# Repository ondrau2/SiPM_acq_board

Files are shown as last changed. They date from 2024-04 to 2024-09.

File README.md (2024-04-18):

Title: Compact multi-channel analyzer for SiPM detectors with real time on-board signal analysis

Most of the commercially available MCAs for SiPM detectors provide precision spectral measurements with costly high-end components. These devices are ideal for accurate instrumentation, however the high complexity makes these devices costly and thus unavailable to wider public. 

The main idea of the presented device is to develop a low-cost MCA which uses widely available of-the-shelf components while providing a spectroscopy of gamma particles with reasonable resolution. The device is based on a STM32G4 family microcontroller, which comprises precision timers with sub-nanosecond resolution, internal embedded analog amplifiers, comparators and up to 4MHz ADC. This significantly reduces required number of external components lowering price and increasing reliability. 

The measurement can be configured by user and may use up to three simultaneous ToT measurements with configurable threshold levels, pulse height measurement, or combination of both. The pulse approximation based on the measured parameters can also be performed to provide peak area measurement. Results can be acquired using various connectivity possibilities such as USB, Ethernet or WiFi. Thanks to the server running on the device the measurement information can be accessed from an internet browser. With an on-board bias power supply only an external power adapter and a SiPM detector with scintillator is needed for measurement.

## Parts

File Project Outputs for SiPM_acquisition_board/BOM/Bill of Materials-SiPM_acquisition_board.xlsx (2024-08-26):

Quantity | Comment | Package | Designator | Distributor | Part Number | Link
40 | 100nF/50V/X7R | 0603 | C1, C4, C5, C11, C25, C28, C30, C32, C43, C44, C45, C46, C55, C56, C57, C58, C68, C69, C71, C72, C74, C75, C76, C77, C78, C84, C86, C89, C91, C94, C96, C99, C102, C105, C107, C108, C109, C110, C111, C118 | Mouser | CC0603KRX7R9BB104, 885012206095 | https://cz.mouser.com/ProductDetail/Yageo/CC0603KRX7R9BB104 https://cz.mouser.com/ProductDetail/Wurth-Electronics/885012206095
9 | D.N.P. | 0603 | C2, C3, C6, C23, C26, C67, C81, C114, C117
21 | 1uF/50V/X5R | 0603 | C7, C10, C14, C16, C21, C22, C24, C27, C52, C61, C63, C64, C83, C85, C88, C90, C93, C95, C98, C101, C104 | Mouser | 810-C1608X5R1H105K | https://cz.mouser.com/ProductDetail/TDK/C1608X5R1H105K080AB?qs=NRhsANhppD%252BLmxnPDqAv3A%3D%3D
4 | 10uF/50V/X5R | 0805 | C8, C12, C33, C34 | Mouser | GRM21BR61H106KE43L | https://cz.mouser.com/ProductDetail/Murata-Electronics/GRM21BR61H106KE43L
1 | 680pF/50V/X5R | 0603 | C9 | Mouser | 77-VJ0603A681JXAAC | https://cz.mouser.com/ProductDetail/Vishay/VJ0603A681JXAAC?qs=sGAEpiMZZMsjJi7B1kCaqWOU2A8fUcuB
1 | 22uF/10V/X5R | 0805 | C13 | Mouser | GRM21BR61A226ME51L | http://cz.mouser.com/ProductDetail/Murata-Electronics/GRM21BR61A226ME51L/
1 | 47nF/100V/X7R | 0603 | C15 | Mouser | 885012206118 | https://cz.mouser.com/ProductDetail/Wurth-Elektronik/885012206118
10 | 10uF/6.3V/X5R | 0603 | C17, C41, C42, C51, C53, C54, C62, C70, C73, C106 | Mouser | C1608X5R0J106M080AB | https://cz.mouser.com/productdetail/tdk/c1608x5r0j106m080ab?qs=sGAEpiMZZMvsSlwiRhF8qsDt8B2LujiHbasHDgpfkEU%3D
1 | 47uF/6V3/X5R | 0603 | C18 | Mouser | ZRB18AR60J476ME01L | https://cz.mouser.com/ProductDetail/Murata-Electronics/ZRB18AR60J476ME01L
1 | 100uF/6V3/X5R | 0805 | C19 | Mouser | GRM21BR60J107ME15L | https://cz.mouser.com/ProductDetail/Murata-Electronics/GRM21BR60J107ME15L
1 | 22uF/6.3V/X5R | 0603 | C20 | Mouser | GRM188R60J226MEA0D | https://cz.mouser.com/productdetail/murata-electronics/grm188r60j226mea0d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
1 | 15nF/50V/X7R | 0603 | C29 | Mouser | GCM188R71H153JA37J | https://cz.mouser.com/ProductDetail/Murata-Electronics/GCM188R71H153JA37J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
1 | 1nF/50V/X7R | 0603 | C31 | Mouser | 06035C102KAT2A | https://cz.mouser.com/ProductDetail/AVX/06035C102KAT2A
1 | 100nF/100V/X7R | 0603 | C35 | Mouser | C0603X104K1RACAUTO | https://cz.mouser.com/ProductDetail/KEMET/C0603X104K1RACAUTO
10 | 1uF/100V/X5R | 0805 | C36, C37, C38, C39, C79, C80, C112, C113, C115, C116 | Mouser | C2012X7S2A105K125AE | https://cz.mouser.com/ProductDetail/TDK/C2012X7S2A105K125AE
1 | 100pF/50V/C0G | 0603 | C40 | Mouser | 885012006057 | https://cz.mouser.com/ProductDetail/Wurth-Elektronik/885012006057?qs=0KOYDY2FL29vJEf4spOyfQ%3D%3D
2 | 10nF/50V/C0G | 0603 | C47, C50 | Mouser | GRM1885C1H103JA01D | http://cz.mouser.com/ProductDetail/Murata-Electronics/GRM1885C1H103JA01D/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
2 | 47pF/50V/C0G | 0603 | C48, C49 | Mouser | 06035A470JAT2A | https://cz.mouser.com/ProductDetail/AVX/06035A470JAT2A
4 | 12pF/50V/C0G | 0402 | C59, C60, C65, C66
6 | 1pF/50V/C0G | 0603 | C82, C87, C92, C97, C100, C103 | Mouser | C0603X109B5GACTU | https://cz.mouser.com/ProductDetail/KEMET/C0603X109B5GACTU?qs=AQlKX63v8Rs4glLobqd%2FJw%3D%3D
3 | BAT54SLT1G | SOT-23 | D1, D2, D4 | Mouser | BAT54SLT1G | http://cz.mouser.com/ProductDetail/ON-Semiconductor/BAT54SLT1G/
1 | 1N4148WS | SOD-323 | D3 | Mouser | 512-1N4148WS | https://cz.mouser.com/ProductDetail/onsemi-Fairchild/1N4148WS?qs=2%2FYqgE%252BHg%252BKBrKZlAsMLhw%3D%3D
1 | 30V | DO-214AC | D5 | TME | P4SMA30A-M2G | https://www.tme.eu/cz/details/p4sma30a-m2g/transil-diody-jednosmerne-smd/taiwan-semiconductor/
1 | SK34AR3G | DO-214AC | D6 | Mouser | 821-SK34AR3G | https://cz.mouser.com/ProductDetail/Taiwan-Semiconductor/SK34A-R3G
1 | ES1D-13-F |  | D7
7 | 5V | 0603 | D8, D9, D10, D11, D12, D13, D14 | Mouser | 652-CG0603MLC-05LEA | https://cz.mouser.com/ProductDetail/Bourns/CG0603MLC-05LEA
1 | 0.5A | 1206 | F1 | Mouser | 652-SF-1206F050-2 | https://cz.mouser.com/ProductDetail/Bourns/SF-1206F050-2
1 | 33R-100 MHz, 3A | 0603 | FB1 | Mouser | 963-BKP1608HS330-T | https://cz.mouser.com/ProductDetail/Taiyo-Yuden/BKP1608HS330-T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
1 | Fuse holder | Holder, 5 mm x 20 mm | FH1 | Mouser | 64600001003 | https://cz.mouser.com/ProductDetail/Littelfuse/64600001003?qs=J2dJc02fMkr9fpR3CPjt3Q%3D%3D
3 | Fiducial |  | FID1, FID2, FID3
3 | SMA, right angle | SMA, right angle | J1, J2, J3 | Mouser | 3-1478978-1 | http://cz.mouser.com/ProductDetail/TE-Connectivity-AMP/3-1478978-1/
1 | 2-pin, 5.08 mm | 2-pin, 5.08 mm | J4 | Mouser | 282841-2 | http://cz.mouser.com/ProductDetail/TE-Connectivity/282841-2/?qs=sGAEpiMZZMvPvGwLNS6713Uge2ImzyUSANpZpjutp6g%3d
1 | DC JACK | TH_CON_PWR_JACK21 | J5 | Farnell | PJ-050AH | https://cz.mouser.com/ProductDetail/CUI/PJ-050AH
1 | 12401899E412A | USB-C | J6 | Mouser | 12401899E412A | https://cz.mouser.com/ProductDetail/Amphenol-Commercial-Products/12401899E412A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
1 | Header, 6-pin | Header, 6-pin | J7 | TME | 67996-206HLF | https://www.tme.eu/cz/details/67996-206hlf/konektory-hrebinky/amphenol-communications-solutions/
3 | 1-port, RJ-45, No LED | RJ-45 | J8, J9, J10 | Mouser | RJSBE5380C1 | https://cz.mouser.com/ProductDetail/Amphenol-Commercial-Products/RJSBE5380C1?qs=LiXFYW4OVo%2FdVDofBGy8HQ%3D%3D
1 | IM01GR | IM01GR | K1 | Mouser | IM01GR | https://cz.mouser.com/ProductDetail/TE-Connectivity-PB/IM01GR?qs=kJlCKCzaZTN1lvAfLPfsqA%3D%3D
5 | 300R@100MHz | 0603 | L1, L4, L5, L6, L7 | Mouser | LI0603D301R-10 | http://cz.mouser.com/ProductDetail/Laird-Technologies/LI0603D301R-10/
1 | 10u/3A | 7.5 x 7.5 x 5.6mm | L2 | Mouser | 673-PA4302.103NLT | https://cz.mouser.com/ProductDetail/Pulse/PA4302103NLT?qs=sGAEpiMZZMvjAcTDbo5QThDFU8CNN5MuDTGY34WQKcE%3D
1 | 100u/0.2A | 7.3 mm x 7.3 mm x 4.55 mm | L3 | Mouser | 580-46104C | https://cz.mouser.com/ProductDetail/EPCOS-TDK/B82432T1104K?qs=%2FkiEPUfD%2Fqmq0lz0mGMkmg%3D%3D&gad_source=1
8 | Green | 0603 | LED1, LED3, LED5, LED6, LED7, LED8, LED9, LED10 | Mouser | 150060VS75000 | https://cz.mouser.com/ProductDetail/Wurth-Elektronik/150060VS75000?qs=LlUlMxKIyB1Q1Bi5mQ%2FKLw%3D%3D
3 | Red | 0603 | LED2, LED4, LED11 | Mouser | 150060RS75000 | https://cz.mouser.com/ProductDetail/Wurth-Elektronik/150060RS75000
4 | 3.2 mm hole |  | PH1, PH2, PH3, PH4
7 | IRLML0030TRPBF | SOT-23 | Q1, Q2, Q4, Q5, Q7, Q9, Q11 | Mouser | IRLML0030TRPBF | https://cz.mouser.com/ProductDetail/Infineon-Technologies/IRLML0030TRPBF
1 | 200 V, 1A |  | Q3
3 | BSS308PEH6327XTSA1 | SOT-23 | Q6, Q8, Q10 | Mouser | BSS308PEH6327XTSA1 | https://eu.mouser.com/ProductDetail/Infineon-Technologies/BSS308PEH6327XTSA1/
34 | 10k/1% | 0603 | R1, R5, R21, R32, R34, R39, R65, R66, R67, R68, R69, R70, R71, R78, R81, R82, R83, R84, R85, R86, R87, R88, R89, R91, R124, R125, R126, R127, R128, R129, R130, R132, R138, R140 | Mouser | RC0603FR-0710KL | https://cz.mouser.com/ProductDetail/Yageo/RC0603FR-0710KL
23 | D.N.P. | 0603 | R2, R6, R10, R15, R17, R19, R20, R36, R96, R99, R101, R102, R106, R108, R109, R113, R115, R116, R118, R120, R122, R137, R145
17 | 0R/1% | 0603 | R3, R7, R12, R13, R38, R51, R63, R64, R95, R100, R107, R114, R119, R121, R123, R136, R144 | Mouser | RC0603FR-070RL | https://cz.mouser.com/ProductDetail/Yageo/RC0603FR-070RL
6 | 50R/1% | 0603 | R4, R8, R14, R98, R105, R112 | Mouser | CRCW060350R0FKEA | http://cz.mouser.com/ProductDetail/Vishay/CRCW060350R0FKEA/?qs=sGAEpiMZZMvdGkrng054txCzvDpDazy7AJnNXXoMwoE%3d
2 | 10R/1% | 0603 | R9, R50 | Mouser | RC0603FR-0710RL | http://cz.mouser.com/ProductDetail/Yageo/RC0603FR-0710RL/?qs=sGAEpiMZZMvdGkrng054t1u4NFGr8RGr6sCAHWQAtFo%3d
1 | 10k | SIP | R11 | Mouser | T93YA103KT20 | https://cz.mouser.com/ProductDetail/Vishay-Sfernice/T93YA103KT20
13 | 220R/1% | 0603 | R16, R30, R58, R59, R72, R73, R74, R75, R76, R77, R103, R110, R117 | Mouser | RC0603FR-07220RL | https://cz.mouser.com/ProductDetail/Yageo/RC0603FR-07220RL
8 | 100R/1% | 0603 | R18, R52, R54, R55, R62, R90, R131, R139 | Mouser | RC0603FR-07100RL | https://cz.mouser.com/ProductDetail/Yageo/RC0603FR-07100RL?qs=sGAEpiMZZMvdGkrng054txdMlaQGj9fiaLtoULAqhv0%3D
1 | 3k9/1% | 1206 | R22 | Mouser | 652-CR1206FX-3901ELF | https://cz.mouser.com/ProductDetail/Bourns/CR1206-FX-3901ELF?qs=raSpJxvwqHF5D5pn75ZoSw%3D%3D
2 | 270k/1% | 0603 | R23, R48 | Mouser | RC0603FR-07270KL | http://cz.mouser.com/ProductDetail/Yageo/RC0603FR-07270KL/?qs=sGAEpiMZZMvdGkrng054t9CkWbSRI0EFj4oHqeYBYBY%3d
2 | 470R/1% | 0603 | R24, R29 | Mouser | RC0603FR-07470RL | http://cz.mouser.com/ProductDetail/Yageo/RC0603FR-07470RL/
1 | 51k/1% | 0603 | R25 | Mouser | RC0603FR-0751KL | http://cz.mouser.com/ProductDetail/Yageo/RC0603FR-0751KL/
2 | 15k/1% | 0603 | R26, R33 | Mouser | RC0603FR-0715KL | http://cz.mouser.com/ProductDetail/Yageo/RC0603FR-0715KL/
1 | 33k/1% | 0603 | R27 | Mouser | RC0603FR-0733KL | http://cz.mouser.com/ProductDetail/Yageo/RC0603FR-0733KL/
1 | 100k/1% | 0603 | R28 | Mouser | RC0603FR-07100KL | https://cz.mouser.com/ProductDetail/Yageo/RC0603FR-07100KL
1 | 68k/1% | 0603 | R31 | Mouser | RC0603FR-0768KL | http://cz.mouser.com/ProductDetail/Yageo/RC0603FR-0768KL/
1 | 12.0k |  | R35 |  | RES_000099
1 | 10.0k |  | R37 |  | RES_000886
2 | 1k/1% | 0603 | R40, R43 | Mouser | RC0603FR-071KL | https://cz.mouser.com/ProductDetail/Yageo/RC0603FR-071KL
1 | 47k/1% | 0603 | R41 | Mouser | CRCW060347K0FKED | https://cz.mouser.com/ProductDetail/Vishay-Dale/CRCW060347K0FKED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
1 | 8k2/1% | 0603 | R42 | Mouser | 603-RC0603FR-078K2L | https://cz.mouser.com/ProductDetail/YAGEO/RC0603FR-078K2L?qs=2cAdsCoAWRETEV2XIsFJNA%3D%3D
1 | 750R/1% | 0603 | R44 | Mouser | RC0603FR-07750RL | http://cz.mouser.com/ProductDetail/Yageo/RC0603FR-07750RL/
1 | 4k7/1% | 0603 | R45 | Mouser | RC0603FR-104K7L | http://cz.mouser.com/ProductDetail/Yageo/RC0603FR-104K7L/
1 | 82k/1% | 0603 | R46 | Mouser | ERJ-3EKF8202V | https://cz.mouser.com/ProductDetail/Panasonic/ERJ-3EKF8202V
1 | 12k/1% | 0603 | R47 | Mouser | 71-CRCW060312K0FKEAC | https://cz.mouser.com/ProductDetail/Vishay/CRCW060312K0FKEAC
4 | 2k/1% | 0603 | R49, R92, R133, R141 | Mouser | ERJ-PA3F2001V | https://cz.mouser.com/ProductDetail/Panasonic/ERJ-PA3F2001V?qs=sGAEpiMZZMtlubZbdhIBIL24R7XL4VFWUbrVHGfRWZU%3D
1 | 0R6/1% | 0603 | R53 | Mouser | RL0603FR-070R6L | https://cz.mouser.com/ProductDetail/YAGEO/RL0603FR-070R6L?qs=k2KEx2DUIRTfFy8xpdt3Ug%3D%3D
10 | 27R/1% | 0603 | R56, R57, R79, R80, R93, R94, R134, R135, R142, R143 | Mouser | 603-RC0603FR-0727RL | https://cz.mouser.com/ProductDetail/Yageo/RC0603FR-0727RL
2 | 5k1/1% | 0603 | R60, R61 | Mouser | RC0603FR-075K1L | https://cz.mouser.com/ProductDetail/Yageo/RC0603FR-075K1L
3 | 2k4/1% | 0603 | R97, R104, R111 | Mouser | RC0603FR-102K4L | https://cz.mouser.com/ProductDetail/Yageo/RC0603FR-102K4L
3 | B3S-1000 | 6 mm x 6 mm | S1, S2, S3 | TME | B3S-1000 | http://cz.mouser.com/ProductDetail/Omron-Electronics/B3S-1000/
1 | TMP275AIDGKR | VSSOP-8 | U1 | Mouser | TMP275AIDGKR | https://cz.mouser.com/ProductDetail/Texas-Instruments/TMP275AIDGKR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
1 | TMUX1121DGKR | VSSOP-8 | U2 | Mouser | TMUX1121DGKR | https://cz.mouser.com/ProductDetail/Texas-Instruments/TMUX1121DGKR?qs=XeJtXLiO41RR8f%2F8dmY7lg%3D%3D
1 | LT3972IMSE#PBF | UMAX-10 | U3 | Mouser | 584-LT3972IMSE#PBF | https://cz.mouser.com/ProductDetail/Analog-Devices-Inc/LT3972IMSEPBF
1 | MAX38908ATD | TDFN-14 | U4 | Mouser | MAX38908ATD | https://cz.mouser.com/ProductDetail/Maxim-Integrated/MAX38908ATD%2b?qs=B6kkDfuK7%2FB7k%2FcmhOO%2F4g%3D%3D
1 | TPS2116DRLR | SOT-5X3-8 | U5 | Mouser | TPS2116DRLR | https://www.snapeda.com/parts/TPS2116DRLR/Texas+Instruments/view-part/?ref=snap
1 | LM51561-Q1 |  | U6
4 | LTC6252 |  | U7, U13, U14, U15
1 | FT230XS-R | SSOP-16 | U8 | Mouser | 895-FT230XS-R | https://cz.mouser.com/ProductDetail/FTDI/FT230XS-R
1 | WIZ850IO | WIZ850IO | U9 | Mouser | 950-WIZ850IO | https://cz.mouser.com/ProductDetail/WIZnet/WIZ850io?qs=W0yvOO0ixfFLSlENQWBCKg%3D%3D
1 | STM32G474RET6 | LQFP-64 | U10 | Mouser | STM32G474RET6 | https://cz.mouser.com/ProductDetail/STMicroelectronics/STM32G474RET6?qs=PzGy0jfpSMvUBs7PMTDqlg%3D%3D
1 | ESP32-S2-SOLO-N4R2 |  | U11
2 | MCP4728-E/UN | MSOP-10 | U12, U19 | Mouser | MCP4728-E/UN | https://cz.mouser.com/ProductDetail/Microchip-Technology/MCP4728-E-UN?qs=E6wAi2XWqcP2zTenScklGA%3D%3D
3 | LMV7271MFX | SOT-23-5 | U16, U17, U18 | Mouser | 926-LMV7271MFX/NOPB | https://cz.mouser.com/ProductDetail/Texas-Instruments/LMV7271MFX-NOPB?qs=7lkVKPoqpbZum5BsCUDxMQ%3D%3D
1 | Header, 6-pin | Header, 6-pin | XPROG1 | TME | T821-1-06-S1 | https://www.tme.eu/cz/details/t821-1-06-s1/konektory-idc/amphenol-communications-solutions/t821106a1s100ceu/
1 | ABM8W-24.0000MHZ-8-B1U-T3 |  | Y1
1 | ECS-.327-6-34S-TR | 3.2 mm x 1.5 mm | Y2 | Mouser | ECS-.327-6-34S-TR | https://cz.mouser.com/ProductDetail/ECS/ECS-327-6-34QS-TR?qs=%2FnKYMpMO73M8kCG5qF34Vw%3D%3D&gad_source=1

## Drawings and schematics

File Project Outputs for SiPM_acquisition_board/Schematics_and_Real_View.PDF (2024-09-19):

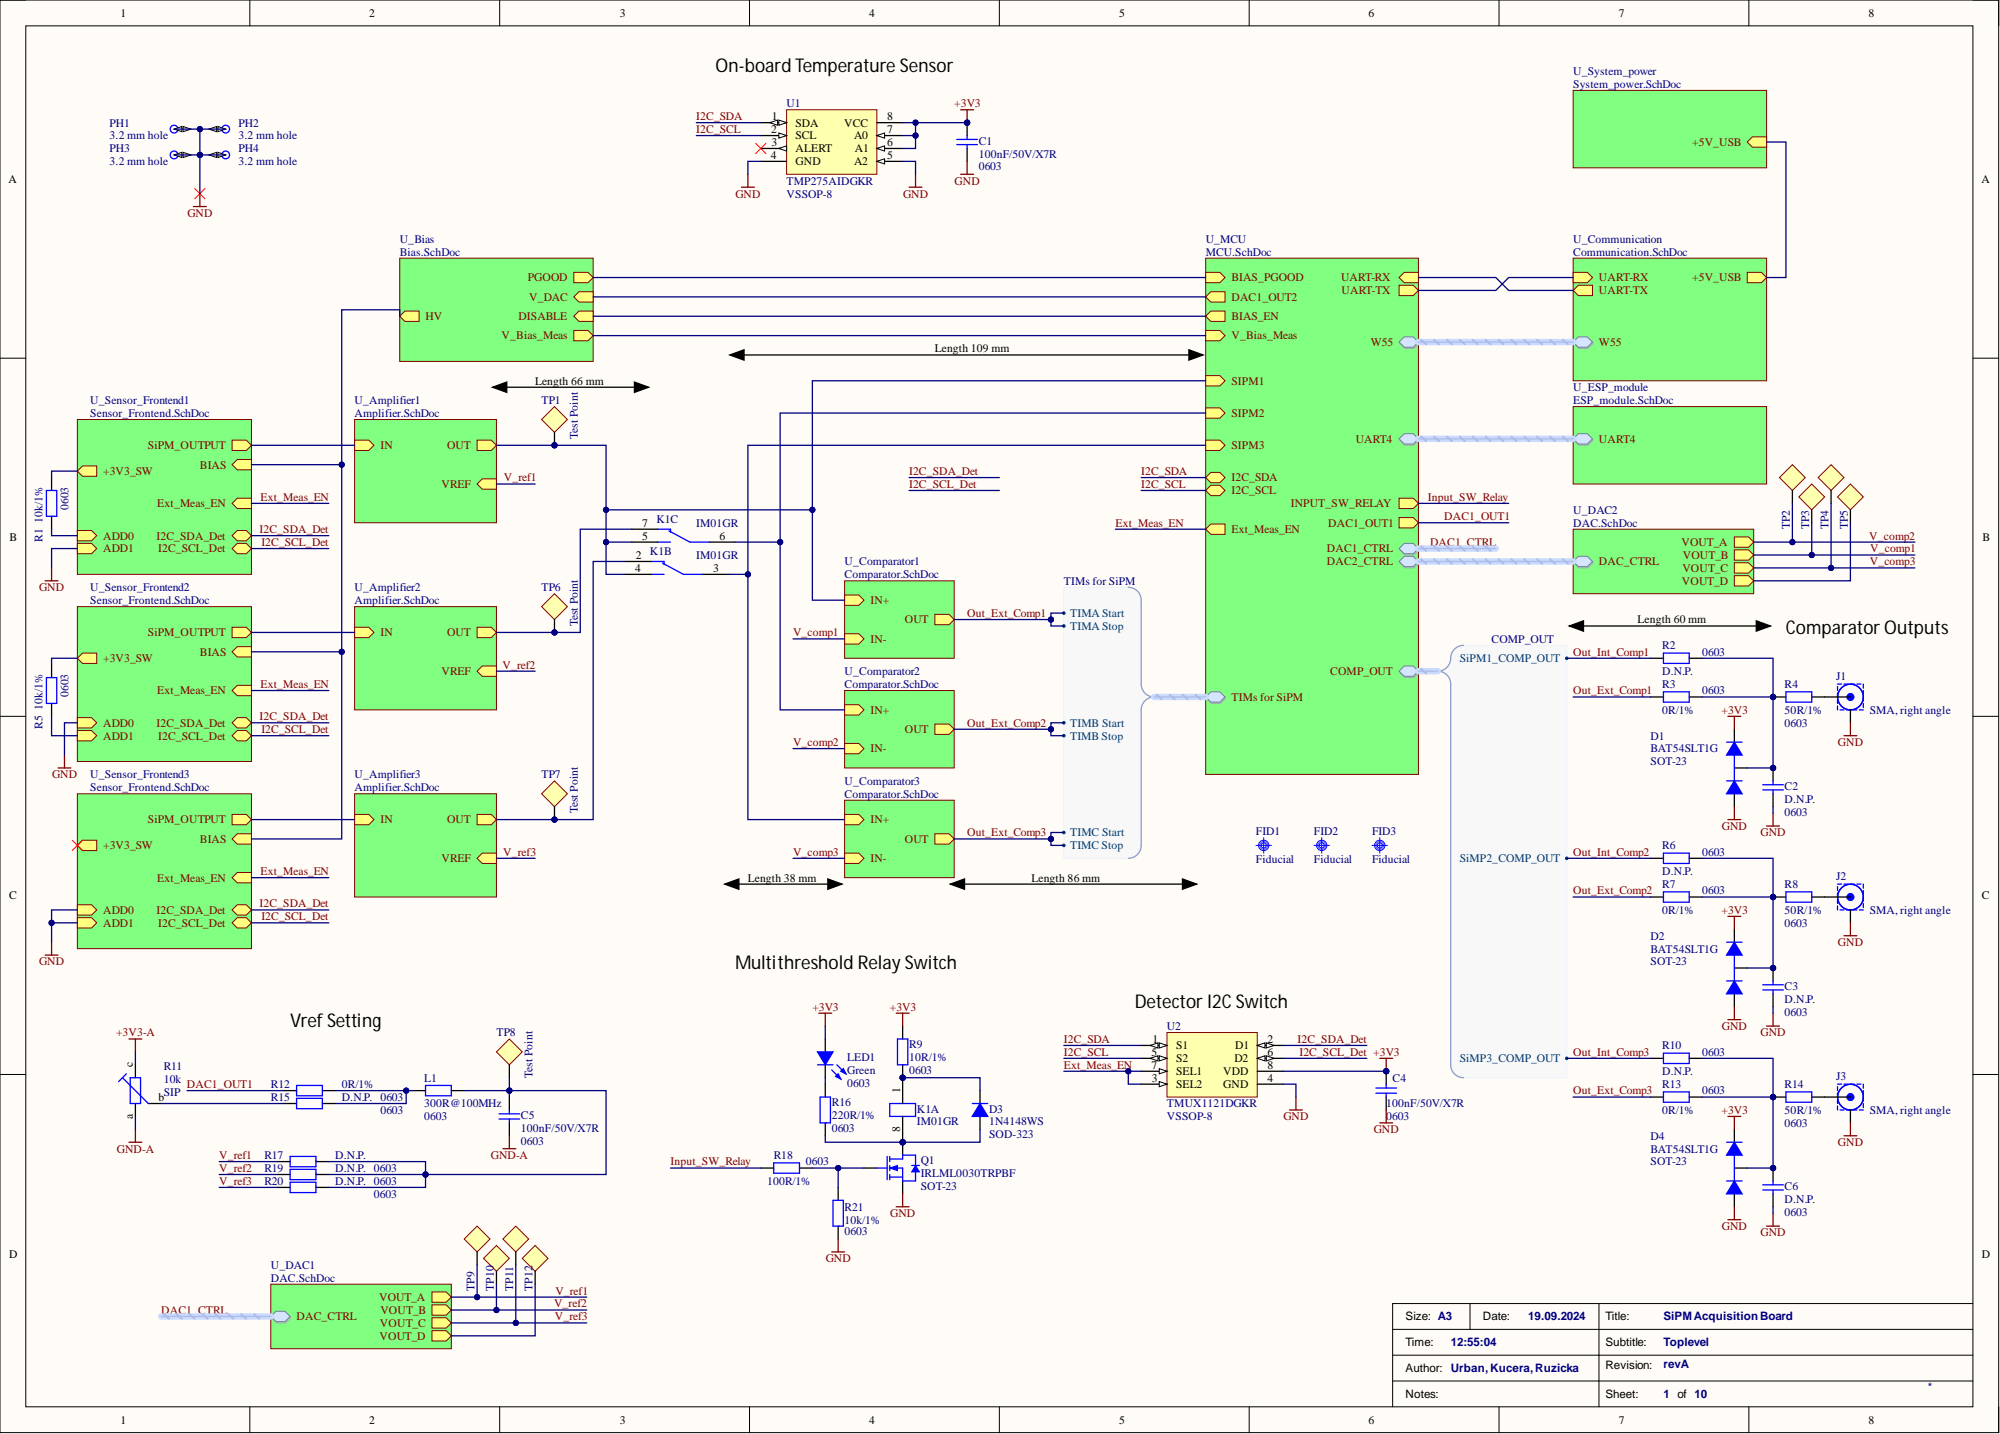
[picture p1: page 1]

_Comparat
TIMC Start TIMB Stop TIMB Start TIMA Stop TIMA Start TIMs for SiPM

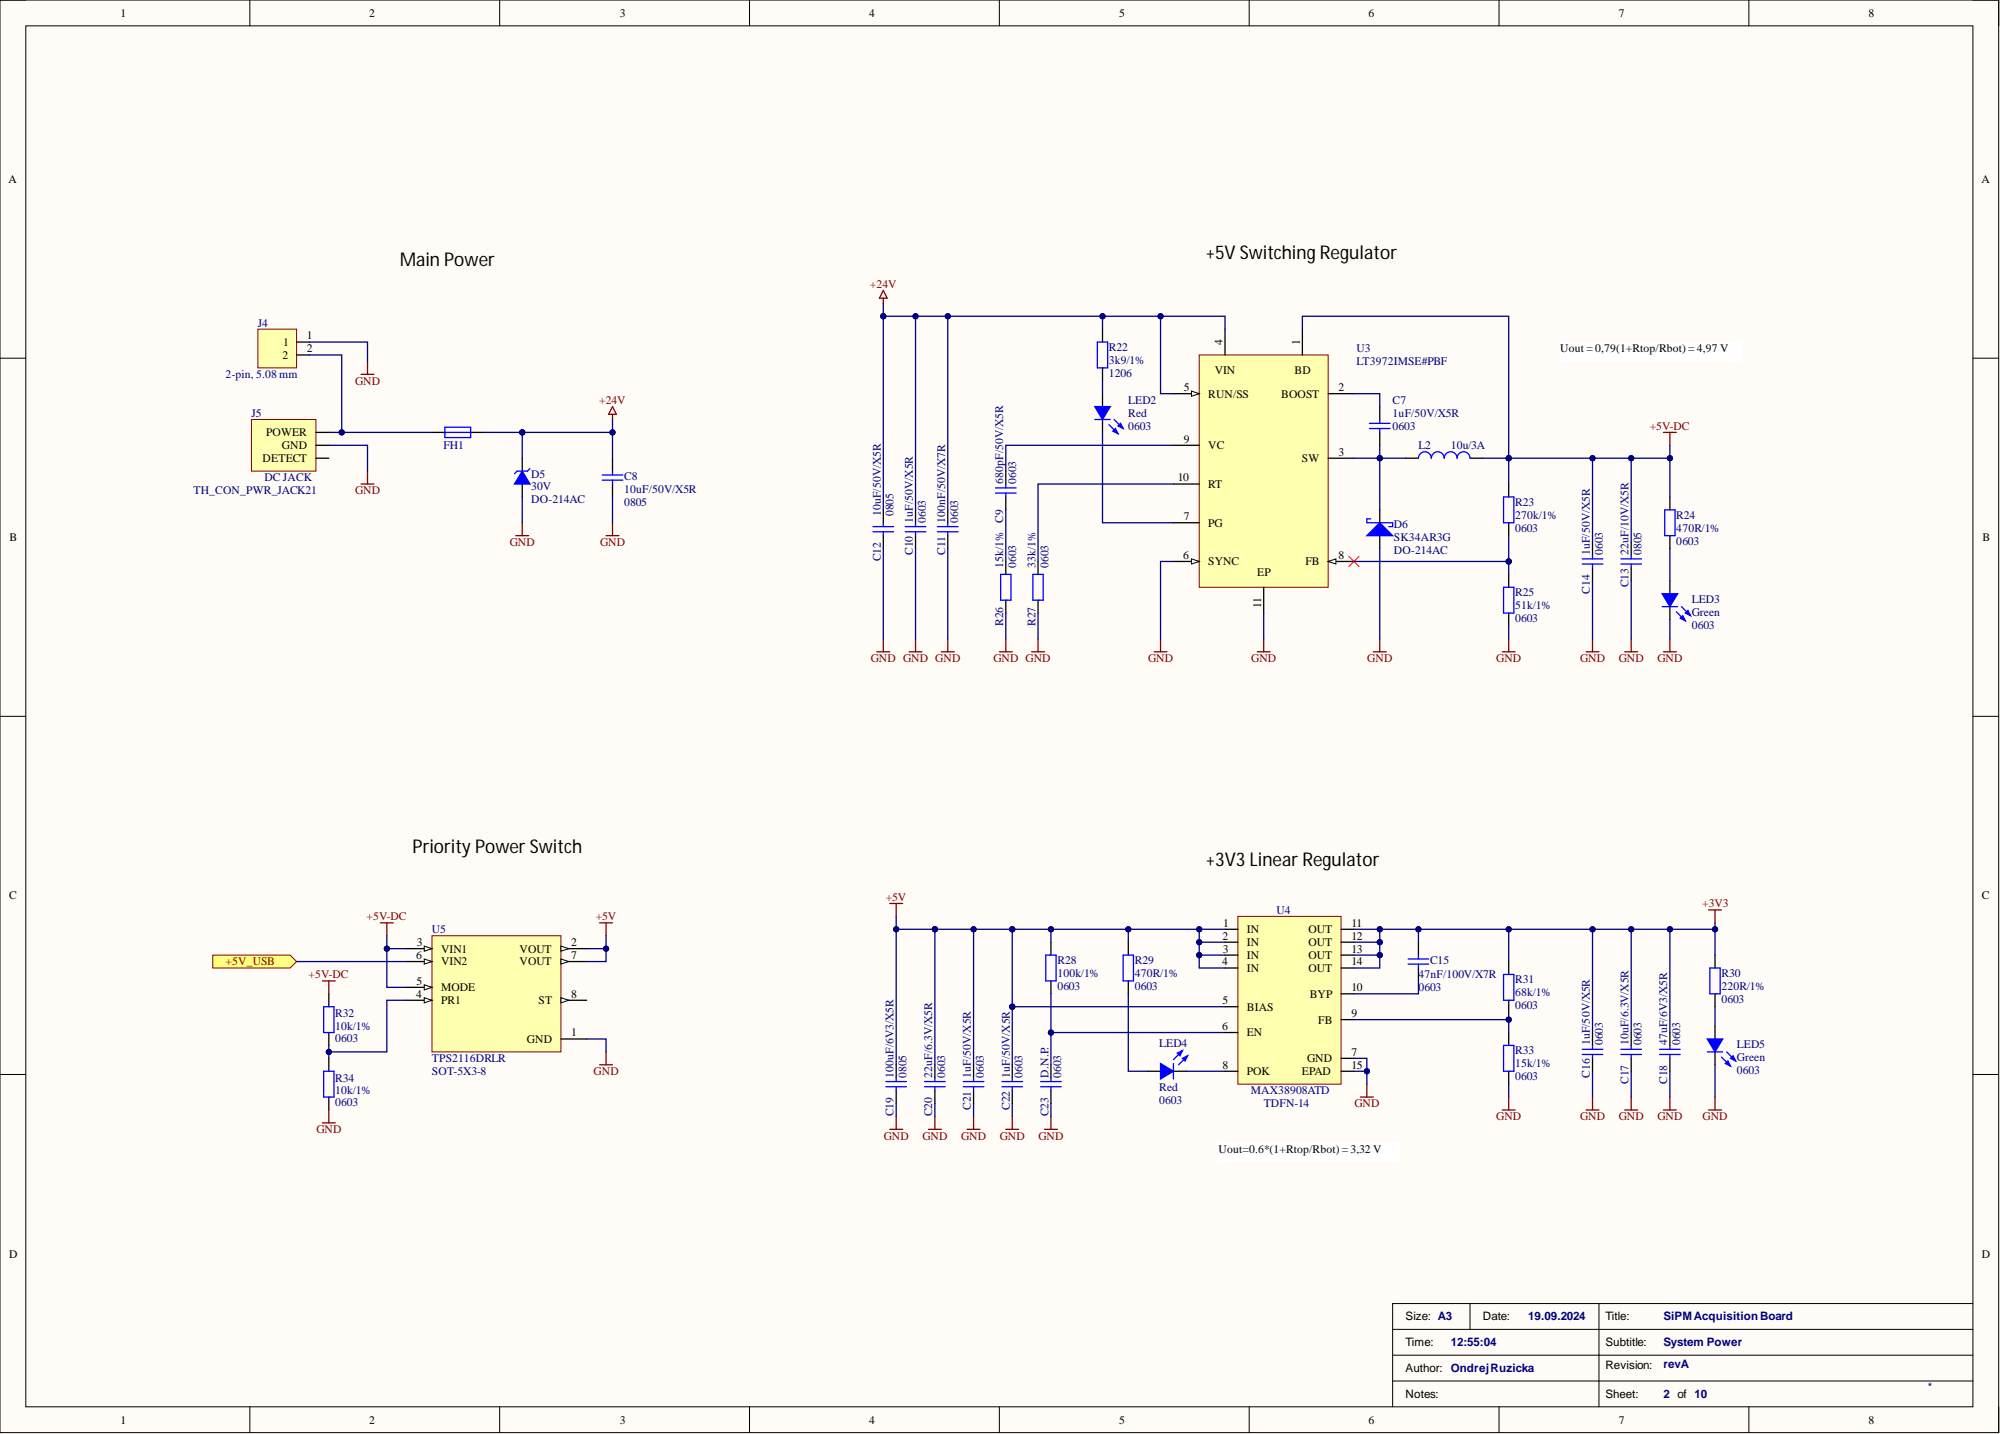
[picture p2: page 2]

2 | 1 2
3 | 1 3
4 | 1 4

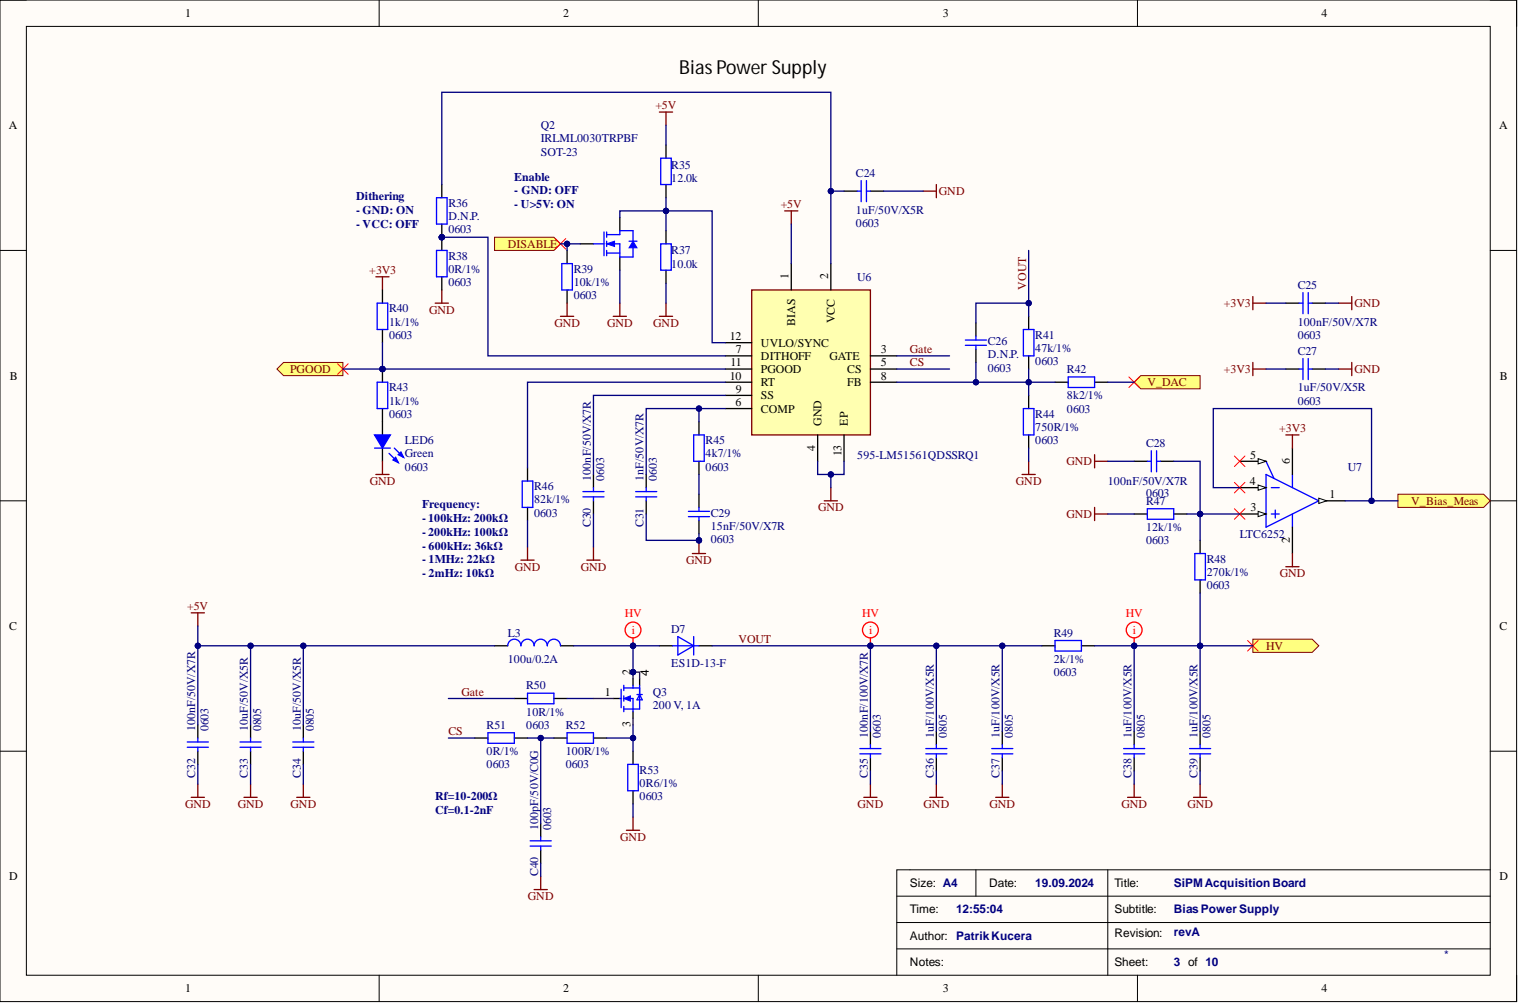
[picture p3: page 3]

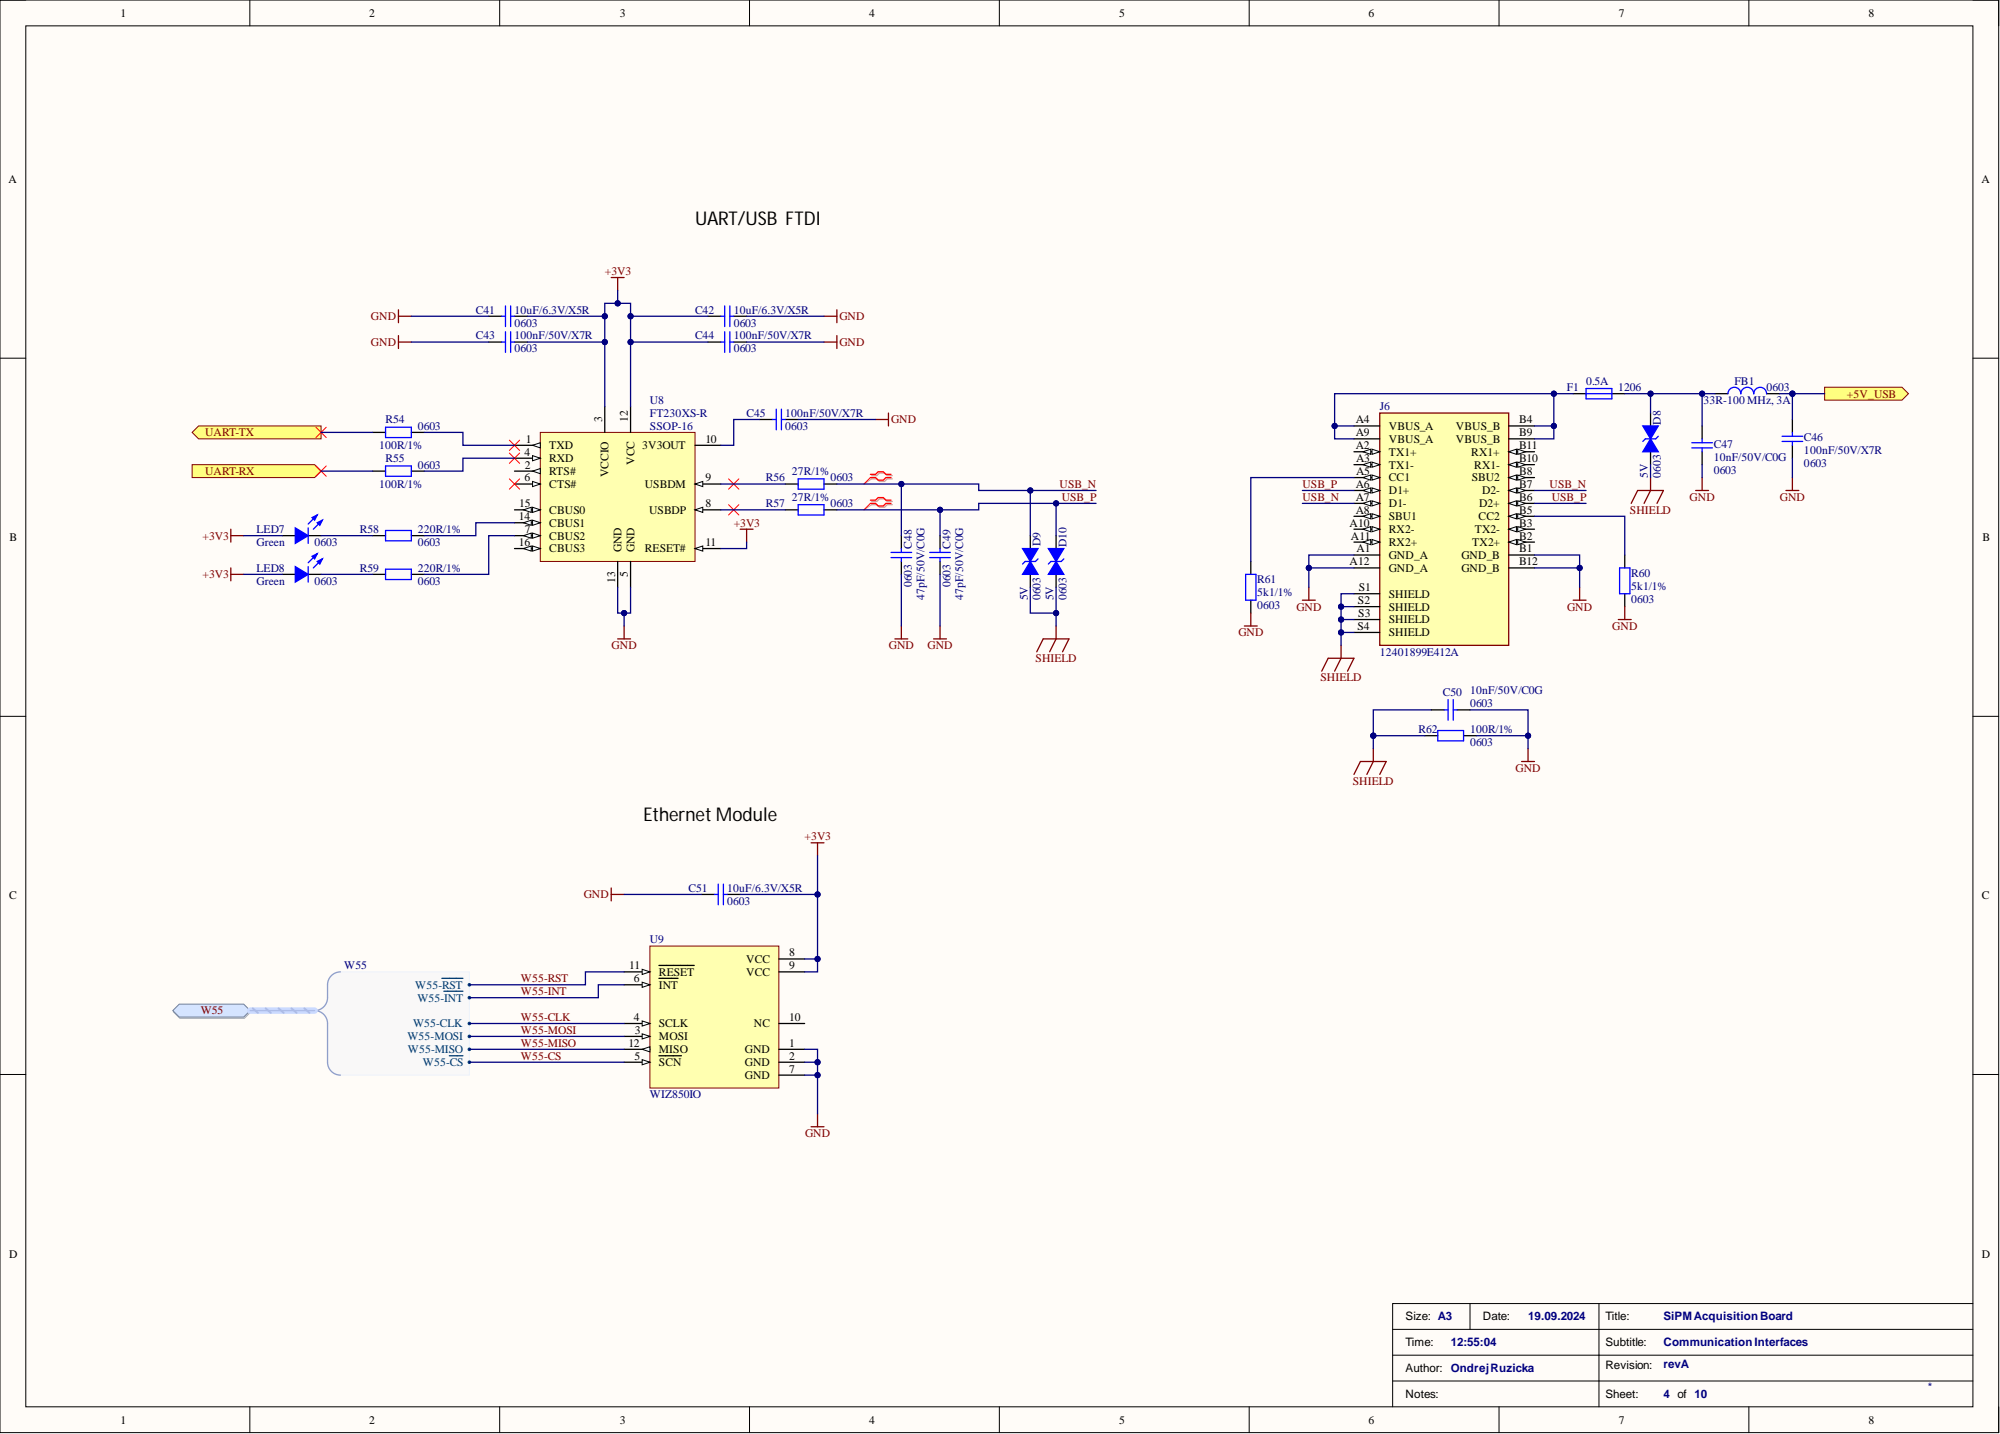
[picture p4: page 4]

RXD 4
RTS# 2

USB_P | D1+ A6 D1- A7 SBU1 A8

CBUS2 7
CBUS3 16

GND_A A12

SHIELD S1
SHIELD S2
SHIELD S3
SHIELD S4

W55-RST | INT 6
W55-INT | SCLK 4

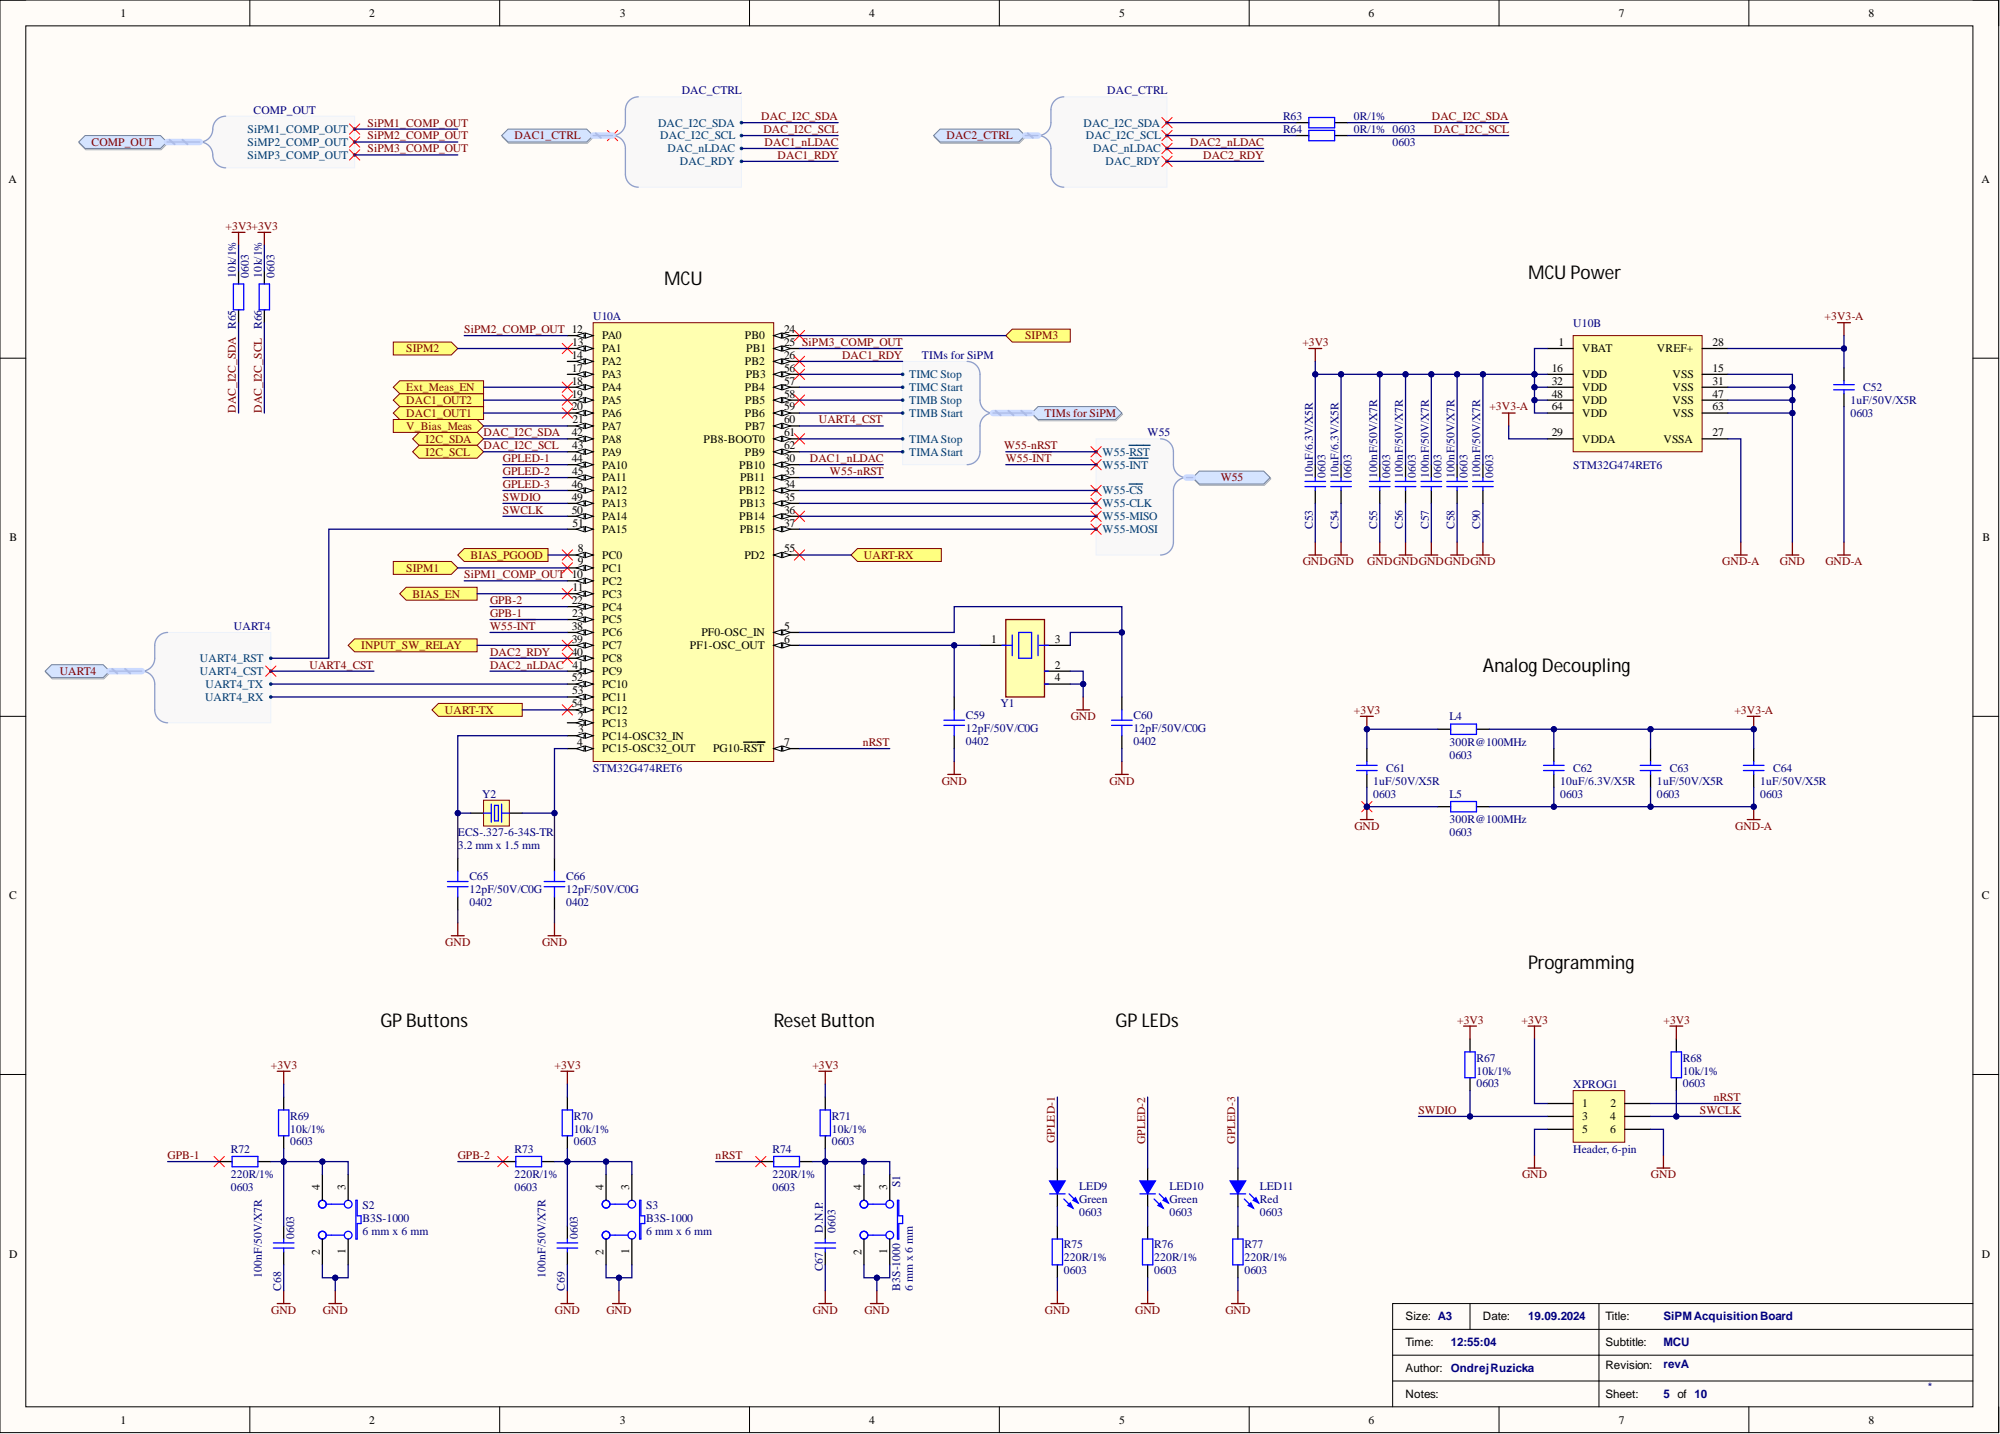
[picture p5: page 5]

C53 10uF/6.3V/X5R GNDGND GNDGNDGNDGND GND-A GND

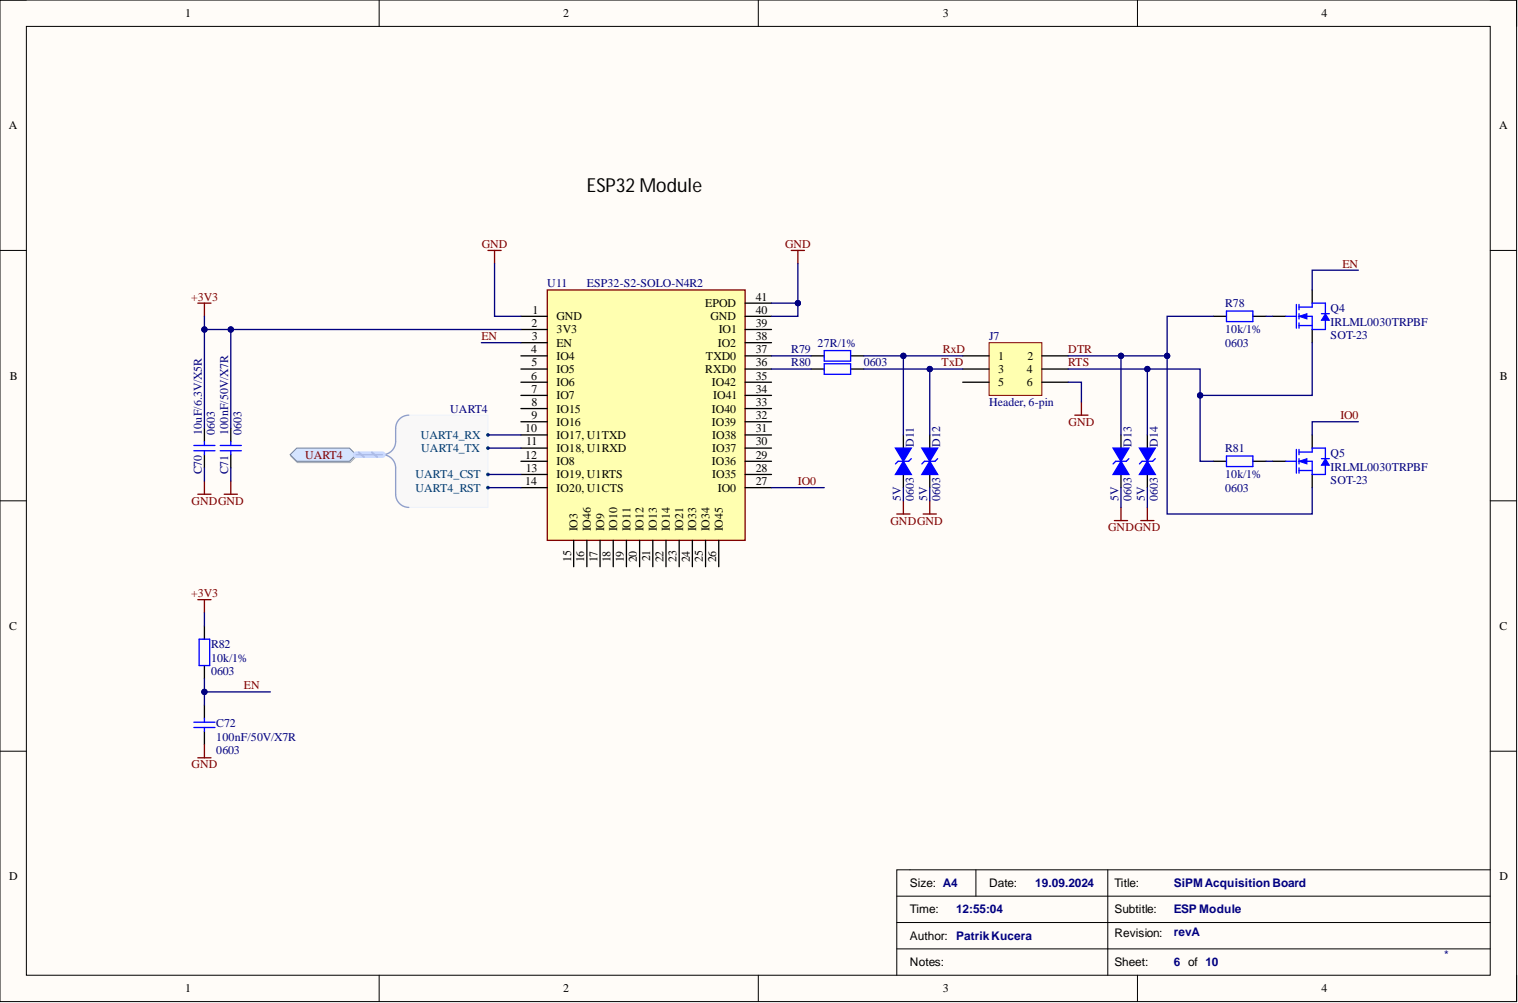
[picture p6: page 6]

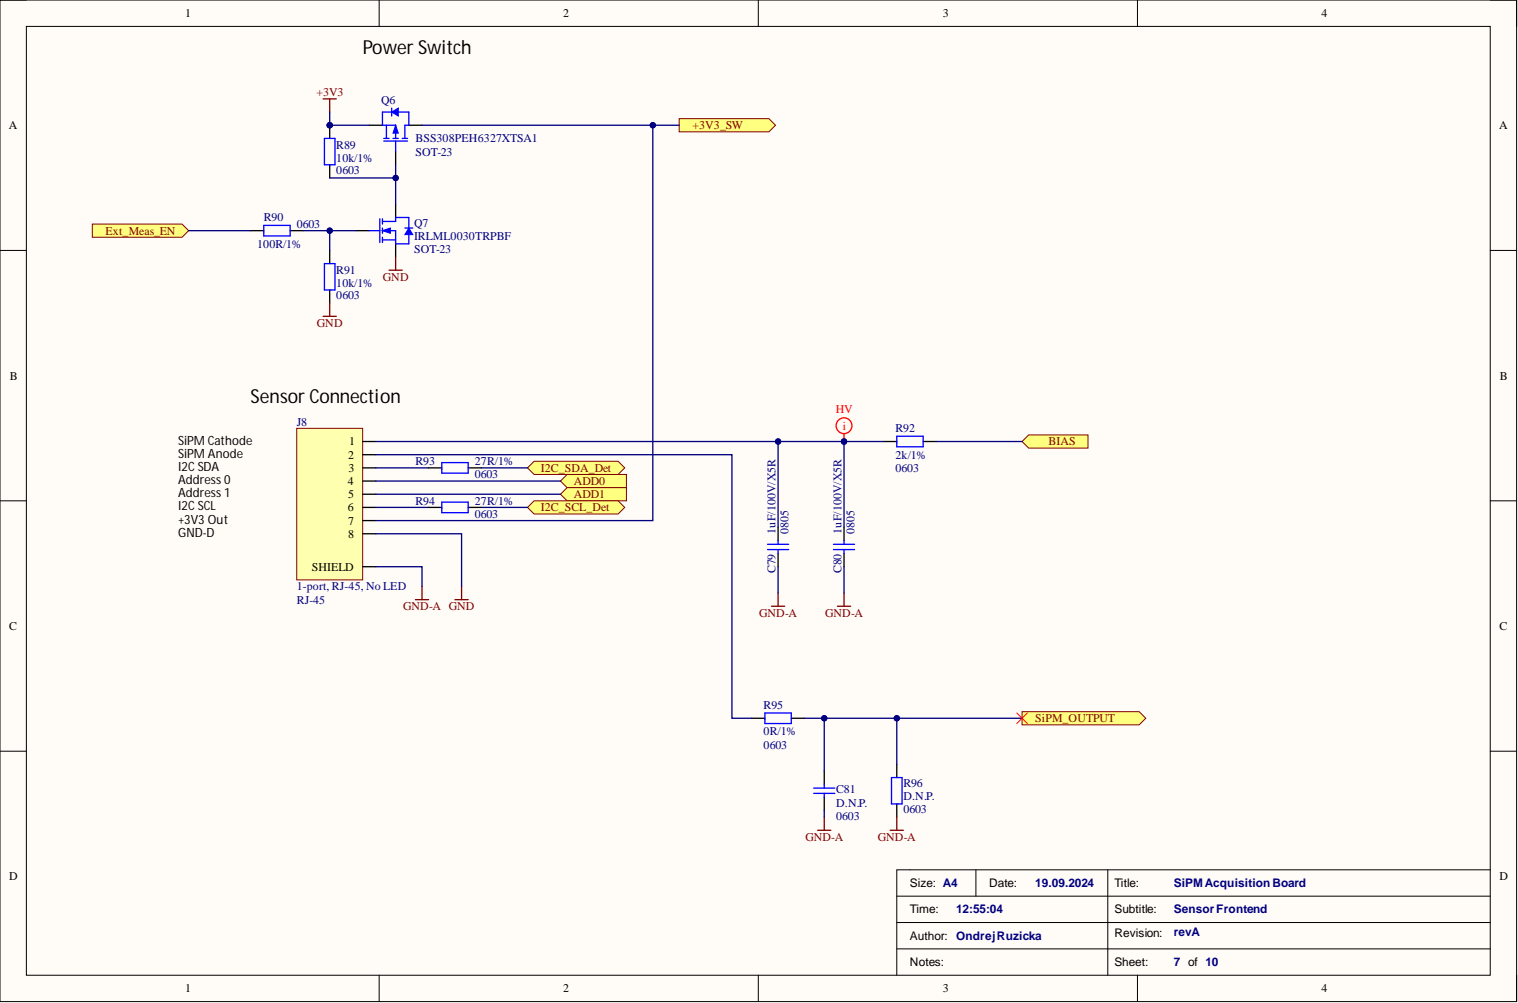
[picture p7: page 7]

SHIELD
1-port, RJ-45, No LED

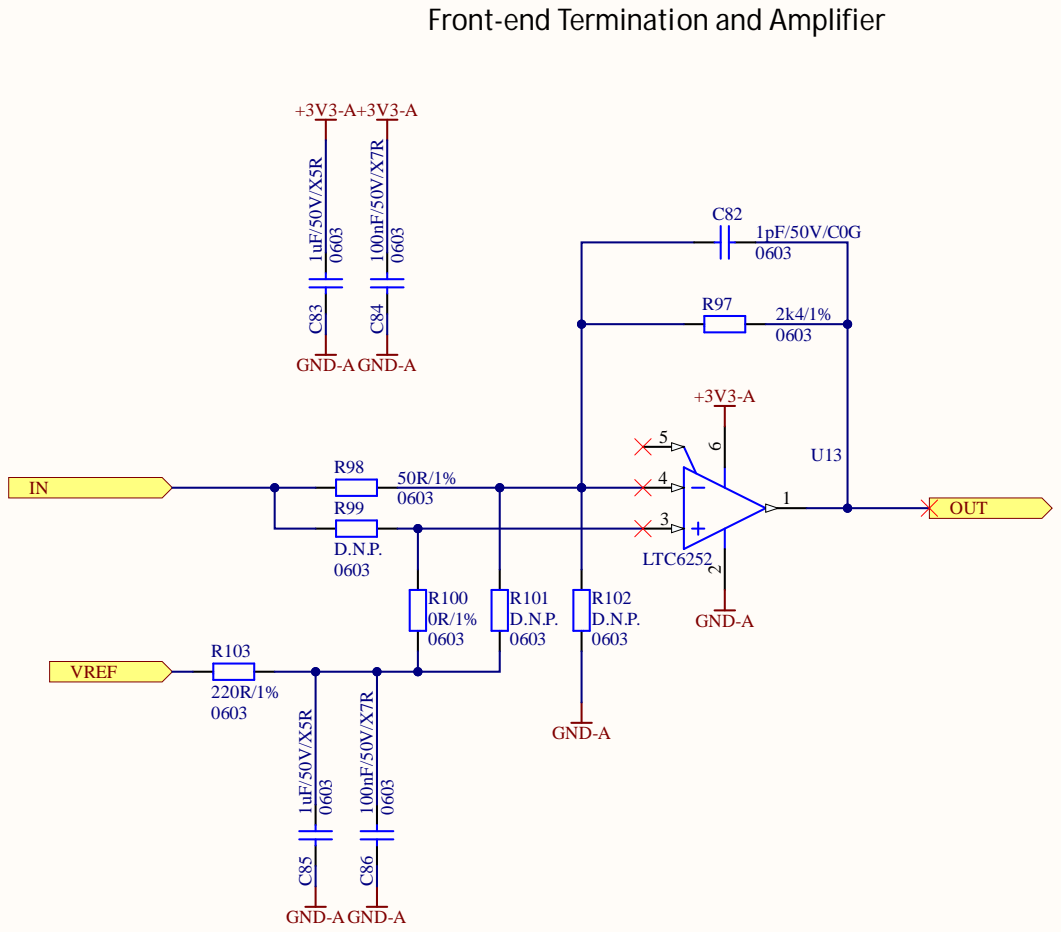
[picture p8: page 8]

Front-end Termination and Amplifier

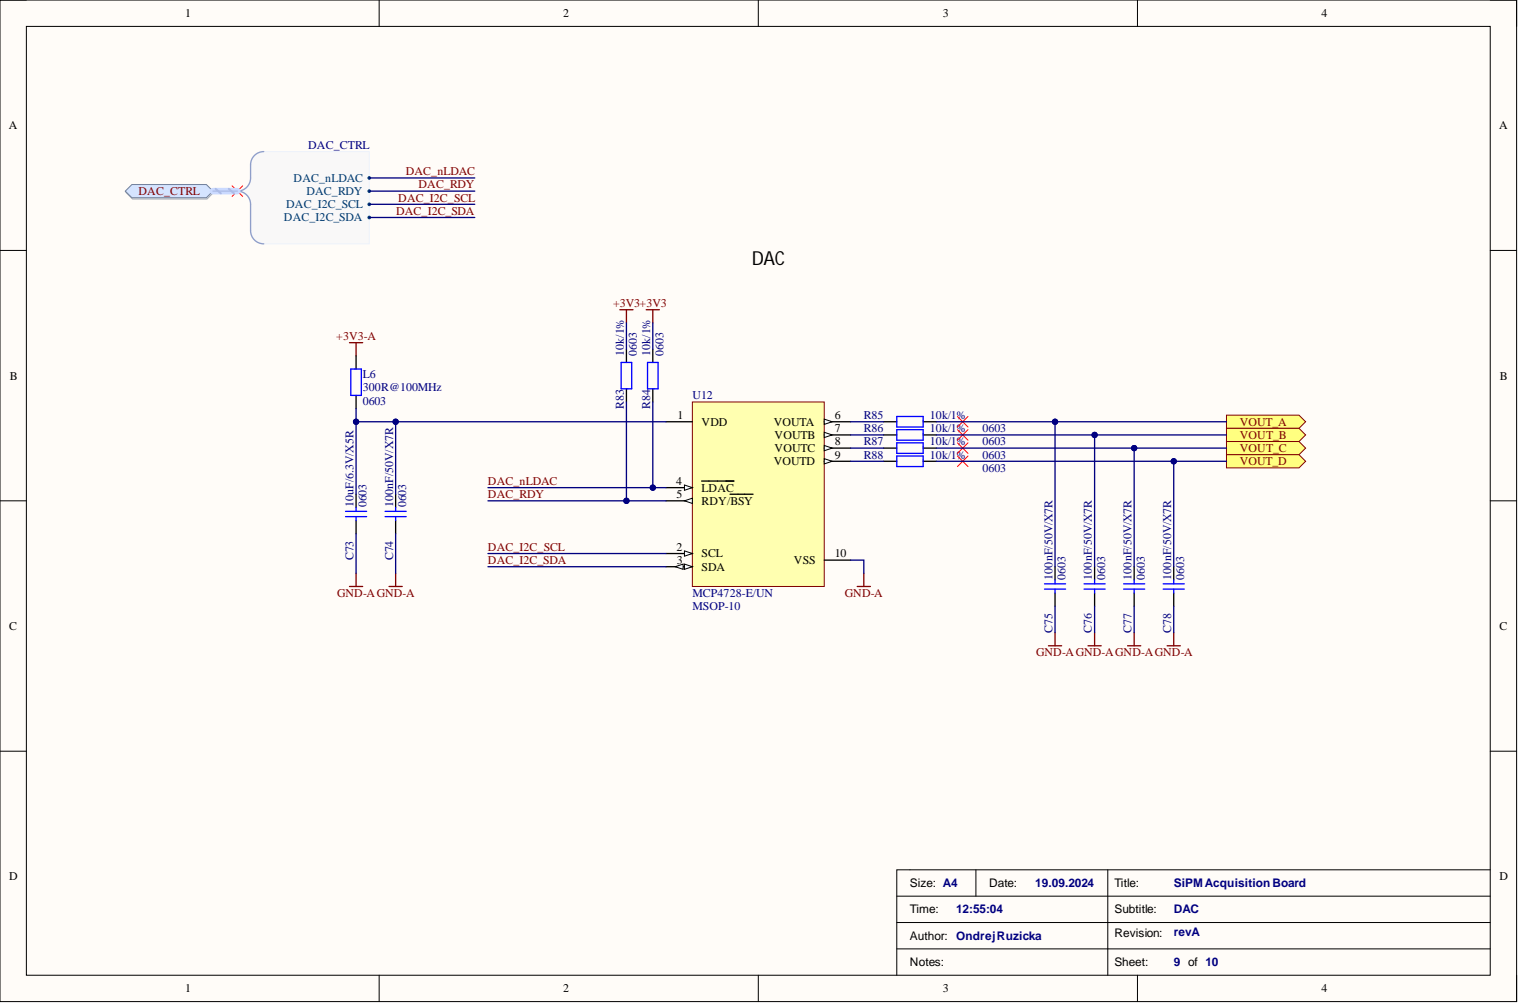
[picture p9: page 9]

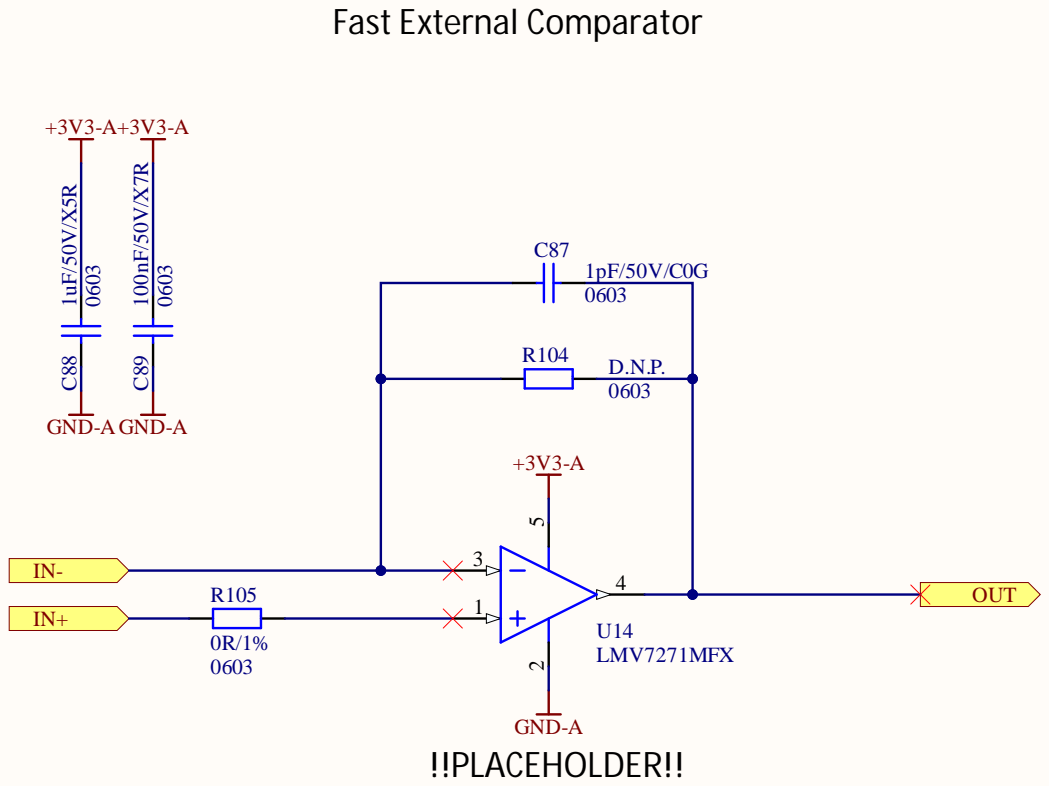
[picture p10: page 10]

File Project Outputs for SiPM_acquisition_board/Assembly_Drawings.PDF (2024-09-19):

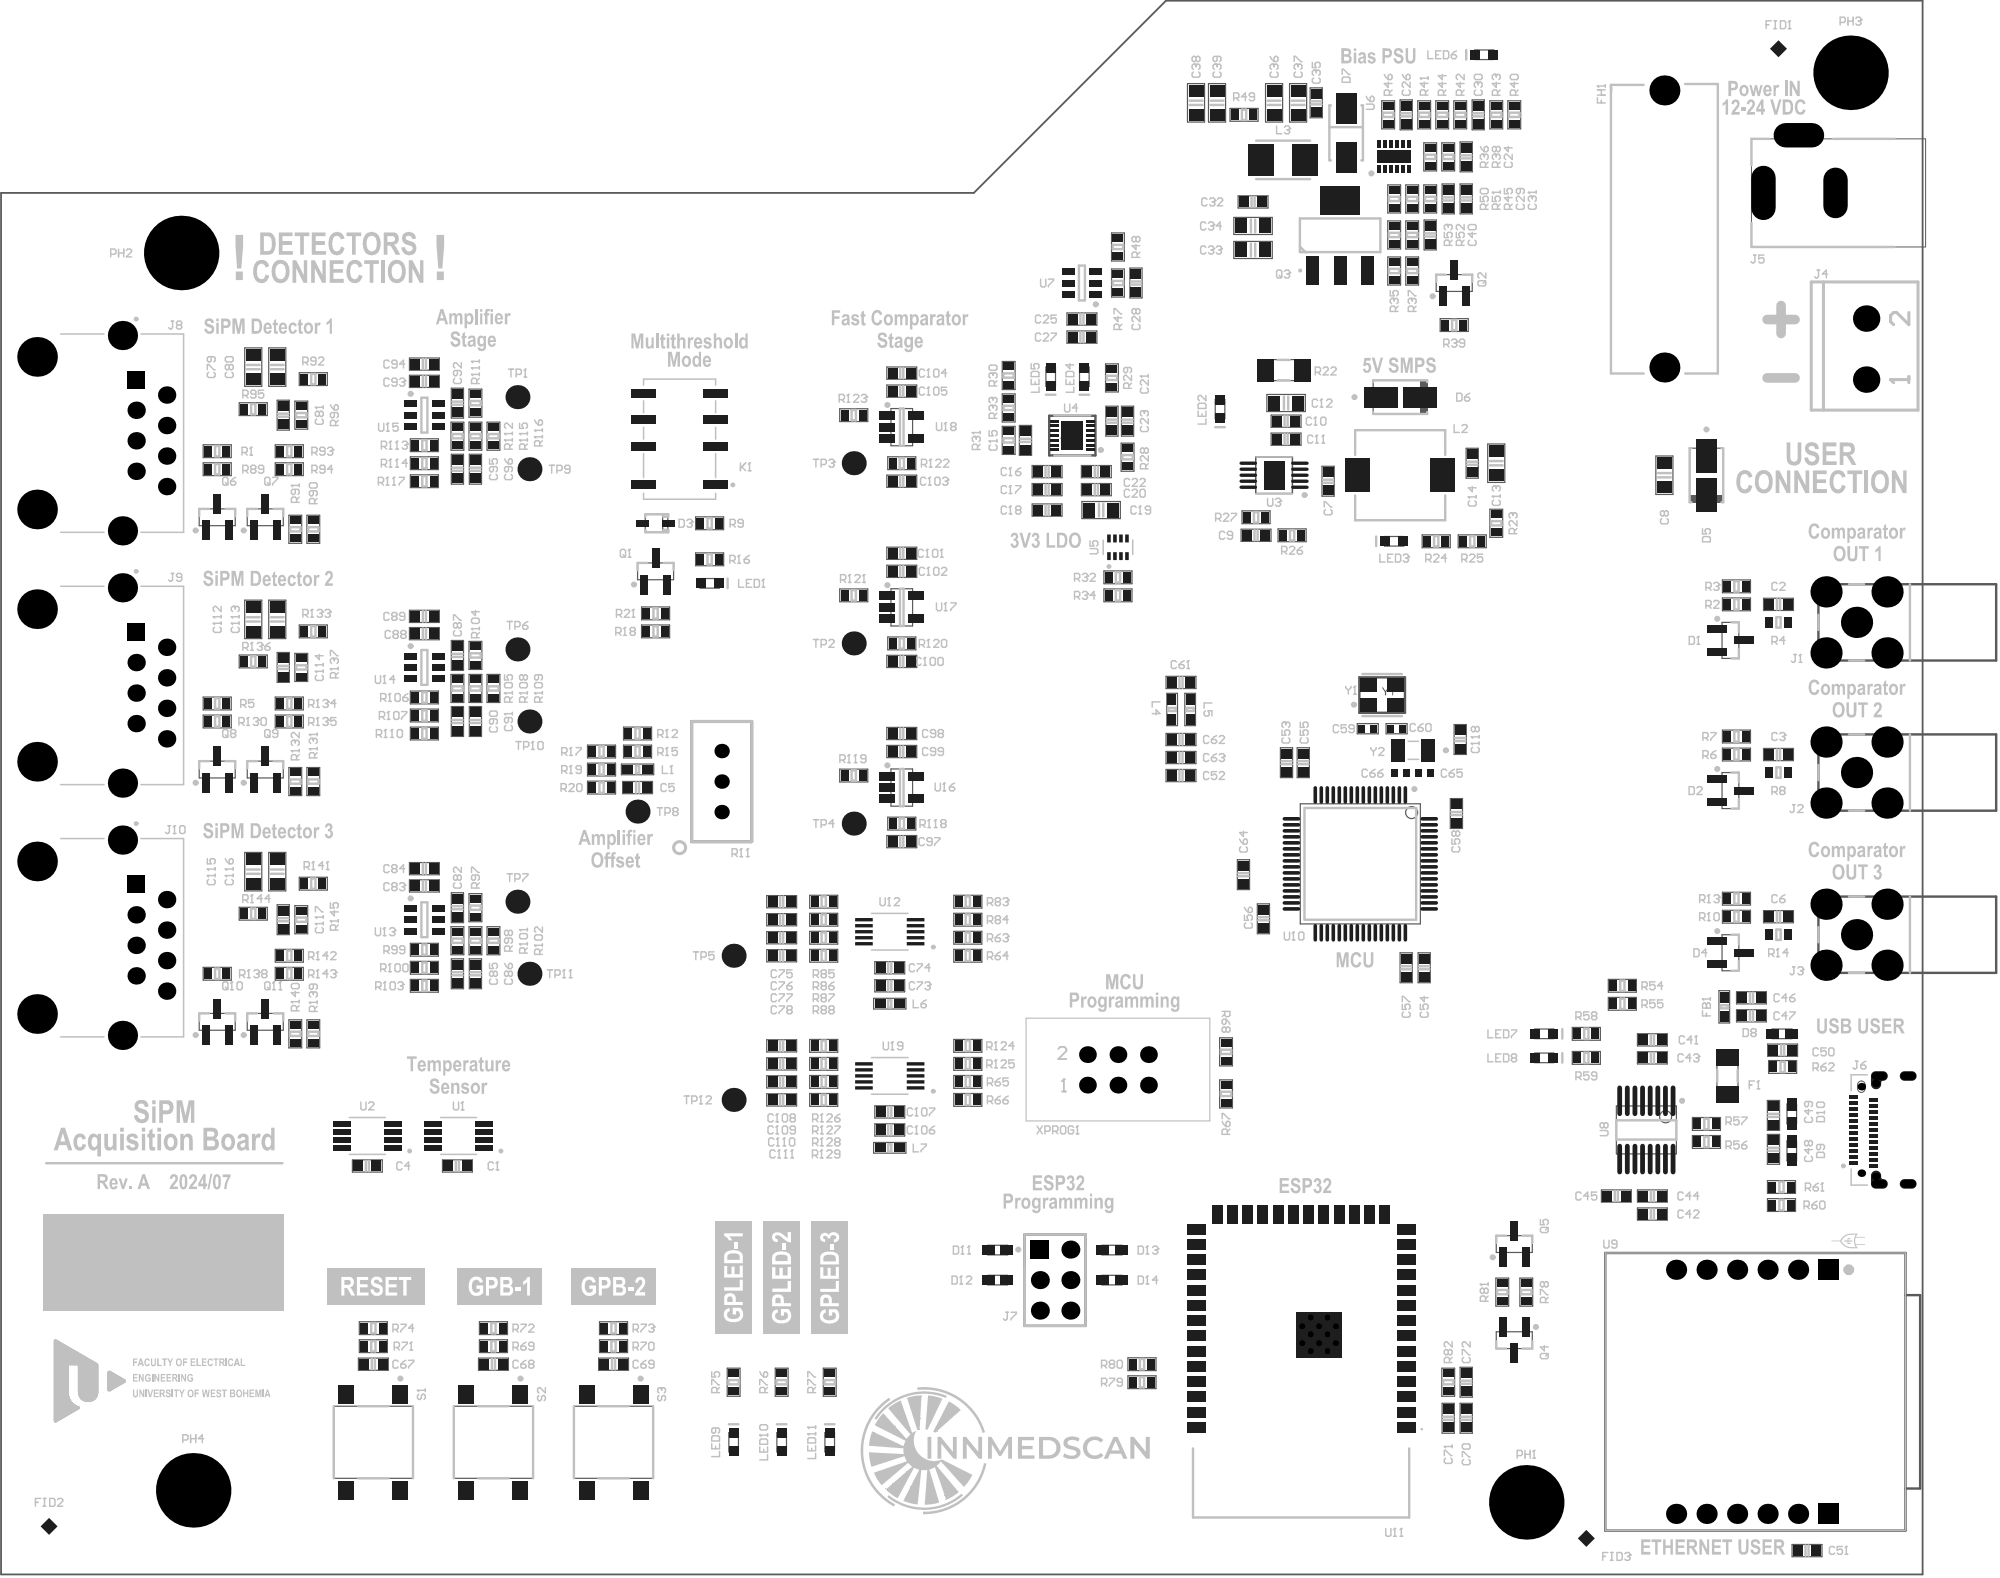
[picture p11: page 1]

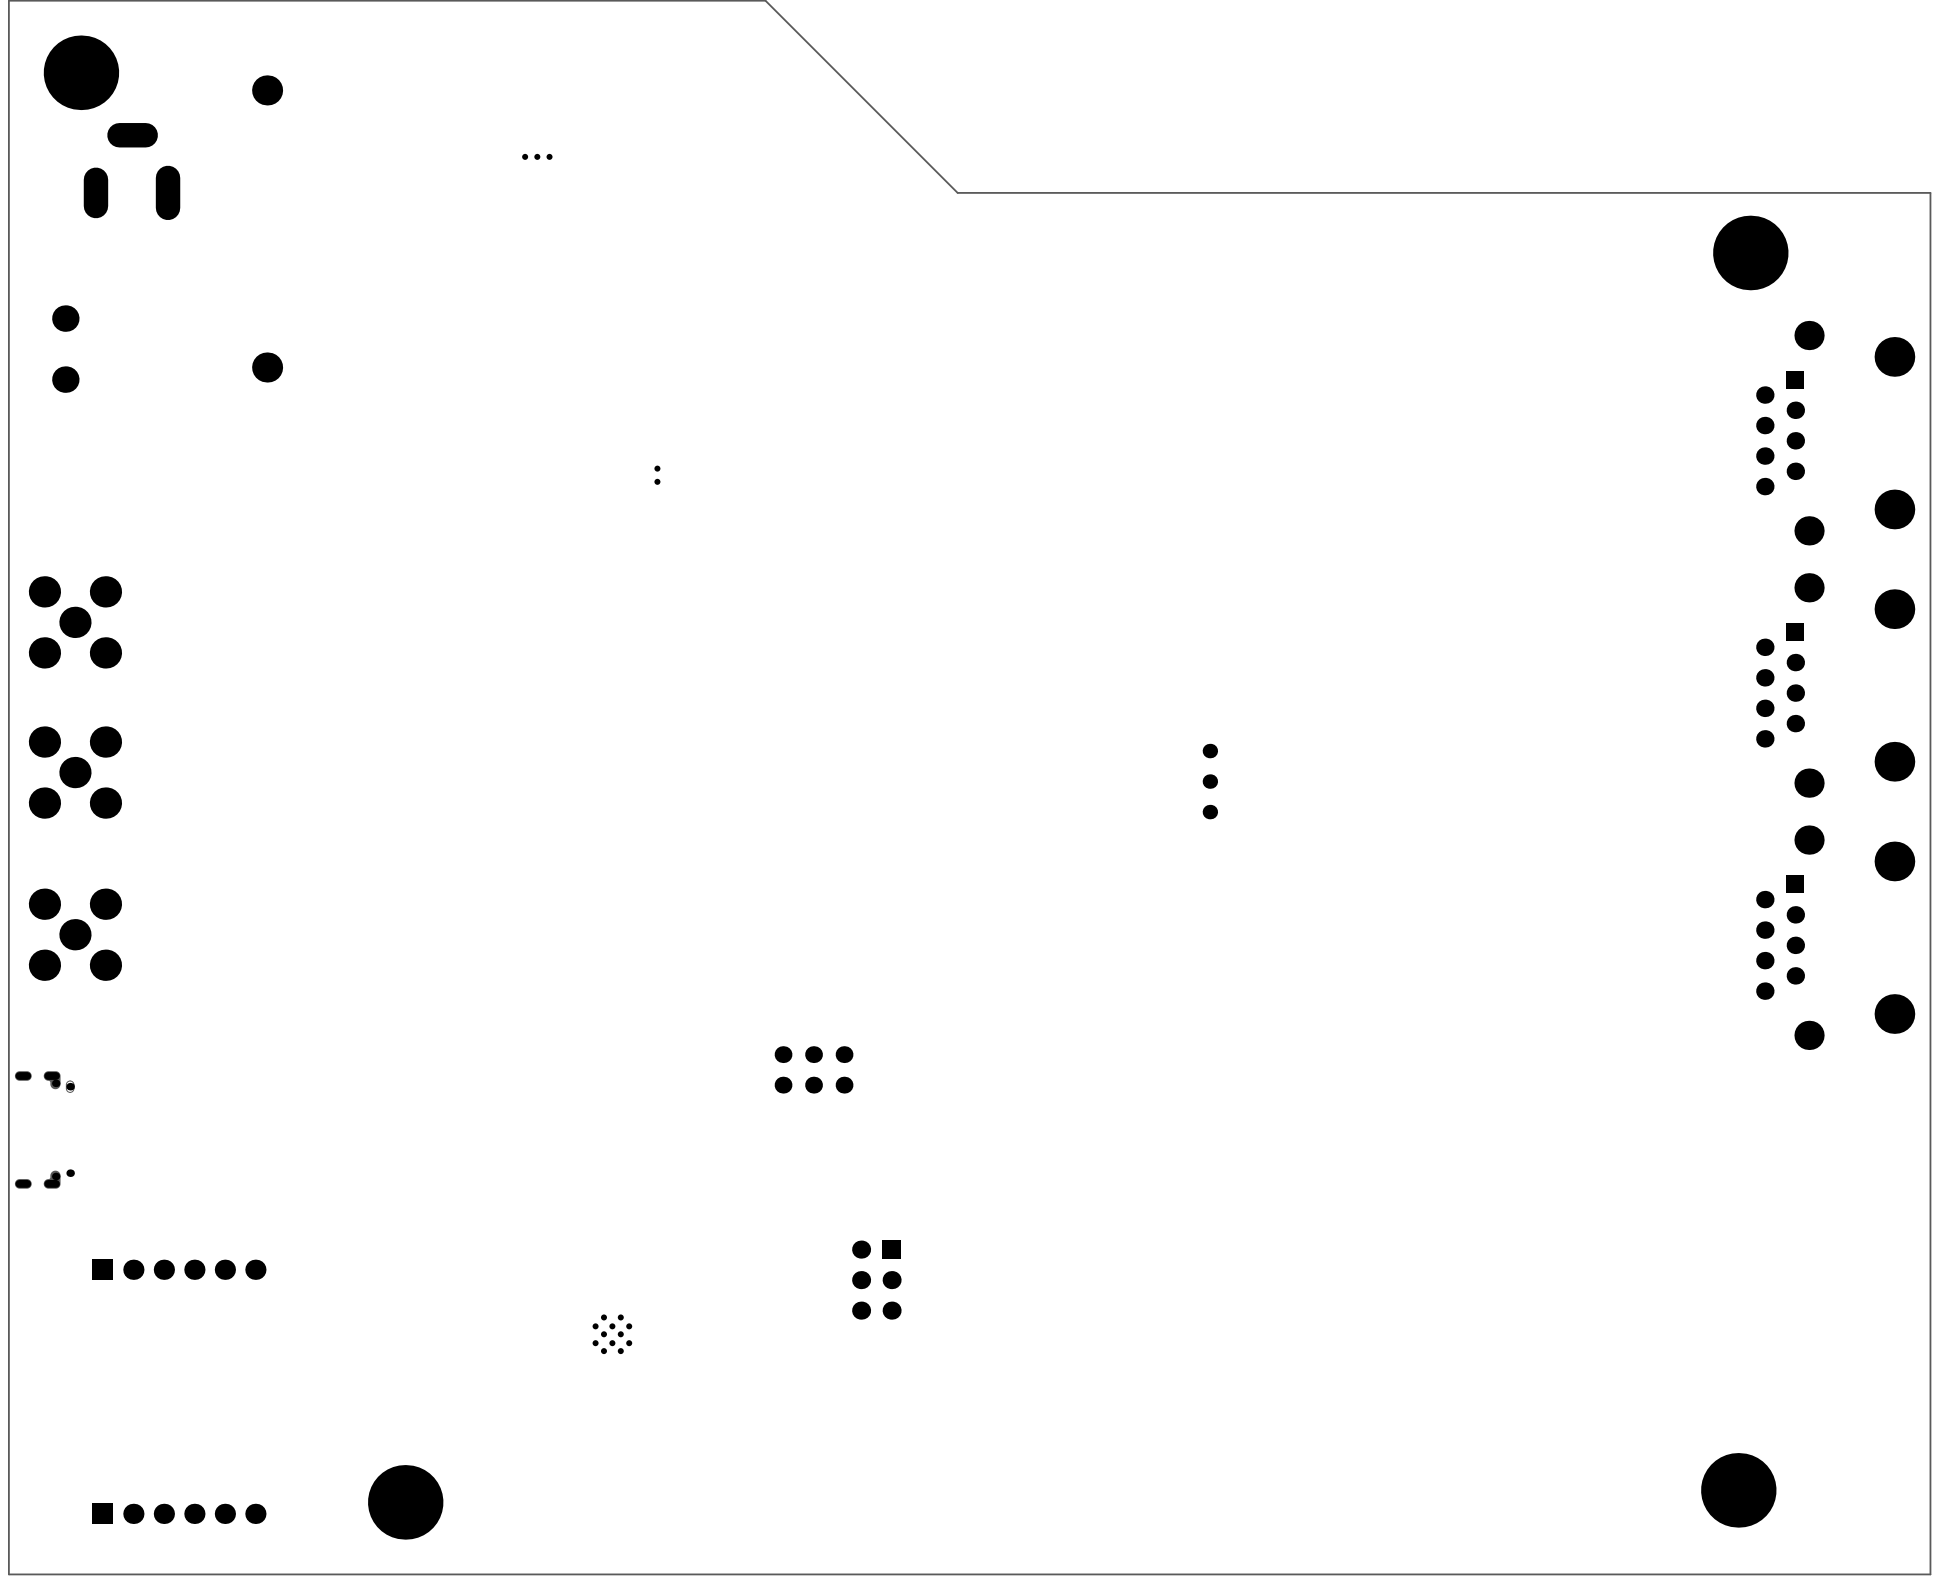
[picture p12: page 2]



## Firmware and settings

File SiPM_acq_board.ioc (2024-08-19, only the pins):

Mcu.UserName=STM32G474RETx
PA0.Signal=COMP1_OUT
PA1.Signal=COMP1_INP
PA10.GPIO_Label=GPLED-1
PA10.Signal=GPIO_Output
PA11.GPIO_Label=GPLED-2
PA11.Signal=GPIO_Output
PA12.GPIO_Label=GPLED-3
PA12.Signal=GPIO_Output
PA13.GPIO_Label=T_SWDIO
PA13.Signal=SYS_JTMS-SWDIO
PA14.GPIO_Label=T_SWCLK
PA14.Signal=SYS_JTCK-SWCLK
PA15.Signal=UART4_RTS
PA2.GPIO_Label=LPUART1_TX
PA2.Signal=LPUART1_TX
PA3.GPIO_Label=LPUART1_RX
PA3.Signal=LPUART1_RX
PA4.GPIO_Label=Ext_Meas_EN
PA4.Signal=GPIO_Output
PA5.Signal=COMP_DAC12_group
PA6.Signal=COMP_DAC21_group
PA7.GPIO_Label=V_Bias_Meas
PA7.Signal=ADC2_IN4
PA8.GPIO_Label=DAC_I2C_SDA
PA8.Signal=I2C2_SDA
PA9.GPIO_Label=DAC_I2C_SCL
PA9.Signal=I2C2_SCL
PB0.Signal=COMP4_INP
PB1.Signal=COMP4_OUT
PB10.GPIO_Label=DAC1_nLDAC
PB10.Signal=GPIO_Output
PB11.GPIO_Label=W55-nRST
PB11.Signal=GPIO_Output
PB12.GPIO_Label=W55_CS
PB12.Signal=GPIO_Output
PB13.GPIO_Label=W55_SPI2_SCK
PB13.Signal=SPI2_SCK
PB14.GPIO_Label=W55_SPI2_MISO
PB14.Signal=SPI2_MISO
PB15.GPIO_Label=W55_SPI2_MOSI
PB15.Signal=SPI2_MOSI
PB2.GPIO_Label=DAC1_RDY
PB2.Signal=GPIO_Output
PB3.Signal=HRTIM1_EEV9
PB4.Signal=HRTIM1_EEV7
PB5.Signal=HRTIM1_EEV6
PB6.Signal=HRTIM1_EEV4
PB7.Signal=UART4_CTS
PB8-BOOT0.Signal=HRTIM1_EEV8
PB9.Signal=HRTIM1_EEV5
PC0.GPIO_Label=BIAS_PGOOD
PC0.Signal=GPXTI0
PC1.Signal=COMP3_INP
PC10.Signal=UART4_TX
PC11.Signal=UART4_RX
PC12.Signal=UART5_TX
PC14-OSC32_IN.Signal=RCC_OSC32_IN
PC15-OSC32_OUT.Signal=RCC_OSC32_OUT
PC2.Signal=COMP3_OUT
PC3.GPIO_Label=BIAS_EN
PC3.Signal=GPIO_Output
PC4.GPIO_Label=GPB-2
PC4.Signal=GPXTI4
PC5.GPIO_Label=GPB-1
PC5.Signal=GPXTI5
PC6.GPIO_Label=W55_INT
PC6.Signal=GPXTI6
PC7.GPIO_Label=INPUT_SW_RELAY
PC7.Signal=GPIO_Output
PC8.GPIO_Label=DAC2_RDY
PC8.Signal=GPIO_Input
PC9.GPIO_Label=DAC2_nLDAC
PC9.Signal=GPIO_Output
PD2.Signal=UART5_RX
PF0-OSC_IN.Signal=RCC_OSC_IN
PF1-OSC_OUT.Signal=RCC_OSC_OUT

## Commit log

2024-04-08 init block fill (Power, Comms, MCU)
    [Ananlog_frontend.SchDoc, Bias.SchDoc, Communication.SchDoc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]
2024-04-18 Create README.md with IWORID abstract
    Added readme, which contains IWORID 2024 abstract.
    It also covers basic idea of the device.
2024-05-30 add Sch lib and PCB lib
    [SiPM_acq_board.PcbLib, SiPM_acq_board.SchLib, SiPM_acquisition_board.PrjPcb]
2024-05-30 Add ESP moudule schematic
    [ESP_module.SchDoc, Top.SchDoc]
2024-05-31 add bias source to schematic
    [Bias.SchDoc, SiPM_acq_board.PcbLib, SiPM_acq_board.SchLib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]
2024-06-04 edit bias source in schematic
    [Bias.SchDoc, SiPM_acq_board.SchLib, Top.SchDoc]
2024-06-07 add analog frontend to schematic
    [Ananlog_frontend.SchDoc, MCU.SchDoc, SiPM_acq_board.PcbLib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]
2024-06-13 add pinout to MCU
    wiznet, ESP, bias
    [ESP_module.SchDoc, MCU.SchDoc, SiPM_acquisition_board.PrjPcb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]
2024-06-14 add MCU pinout
    I2C for external DAC and External events for SiPM
    [MCU.SchDoc, SiPM_acquisition_board.PrjPcb]
2024-06-14 toplevel relay progress
    [Top.SchDoc]
2024-06-14 DAC added
    [DAC.SchDoc, MCU.SchDoc, SiPM_acquisition_board.PrjPcb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]
2024-06-14 DAC implemented
    [Comparator.SchDoc, DAC.SchDoc, MCU.SchDoc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]
2024-06-14 add MCU pinout
    internal comp output, relay GPIO and control for external DAC
    [MCU.SchDoc]
2024-06-14 comparator added, schematic cleanup
    [Amplifier.SchDoc, Comparator.SchDoc, MCU.SchDoc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]
2024-06-16 schematic cleanup
    [Sensor_Frontend.SchDoc, Top.SchDoc]
2024-06-19 uniforming schematic
    [Bias.SchDoc, Communication.SchDoc, ESP_module.SchDoc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]
2024-06-20 schematic progress
    [Amplifier.SchDoc, Bias.SchDoc, Communication.SchDoc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]
2024-06-25 annotation, init pcb added
    [Amplifier.SchDoc, Bias.SchDoc, Communication.SchDoc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]
2024-06-25 PCB initial grouping
    [Amplifier.SchDoc, Bias.SchDoc, Communication.SchDoc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]
2024-06-26 rough placement PCB
    [Amplifier.SchDoc, Comparator.SchDoc, MCU.SchDoc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]
2024-06-26 board outline
2024-06-26 pcb progress
    [MCU.SchDoc, SiPM_acquisition_board.PrjPcb]
2024-06-27 MCU pin remapping, PCB layout progress
    [MCU.SchDoc, Top.SchDoc]
2024-06-27 frontend RJ45
    [MCU.SchDoc, Sensor_Frontend.SchDoc]
2024-06-27 frontend conn expanded
    [MCU.SchDoc, Sensor_Frontend.SchDoc, Top.SchDoc]
2024-06-28 PCB progress, pin map
    [DAC.SchDoc, MCU.SchDoc, Sensor_Frontend.SchDoc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]
2024-06-30 init routing finished
    [SiPM_acquisition_board.PrjPcb]
2024-06-30 sma footprint changed
2024-07-01 temp sensor schematic added
    [MCU.SchDoc, Top.SchDoc]
2024-07-01 tmp sensor added
    [Top.SchDoc]
2024-07-01 temp sensor routed
    [Top.SchDoc]
2024-07-01 annotation, length matching added
    [Amplifier.SchDoc, Bias.SchDoc, Communication.SchDoc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]
2024-07-01 silkscreen, length matching
    [Top.SchDoc]
2024-07-02 schematic ERC cleanup
    [Amplifier.SchDoc, Bias.SchDoc, Communication.SchDoc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]
2024-07-02 DRC cleanup
    [ESP_module.SchDoc, SiPM_acq_board.PcbLib]
2024-07-04 minor changes
    [SiPM_acquisition_board.PrjPcb]
2024-08-14 edit CubeMX based on schematic change
2024-08-19 add bias voltage ADC measurement
    [Bias.SchDoc, MCU.SchDoc, Top.SchDoc]
2024-08-23 i2c switch added, USB-C added, power priority
    [Bias.SchDoc, Communication.SchDoc, Comparator.SchDoc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]
2024-08-23 review ready
    [Amplifier.SchDoc, Bias.SchDoc, Communication.SchDoc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]
2024-08-23 add 24MHz crystal to sch and PCB lib
    [SiPM_acq_board.PcbLib, SiPM_acq_board.SchLib]
2024-08-23 board annotation from last changes
2024-08-24 change crystal to 24 MHz and add cap to 32KHz crystal
    [MCU.SchDoc, SiPM_acq_board.SchLib, SiPM_acquisition_board.PrjPcb]
2024-08-25 reannotate board
    [Amplifier.SchDoc, Bias.SchDoc, Communication.SchDoc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]
2024-08-25 edit bias source
    change input voltage to 5V
    replace transistor and diode
    [Bias.SchDoc, SiPM_acq_board.PcbLib, SiPM_acq_board.SchLib]
2024-08-25 edit ULVO divider for bias IC for 5V
    [Bias.SchDoc, SiPM_acquisition_board.PrjPcb]
2024-08-26 vbat cap added
    [Bias.SchDoc, MCU.SchDoc]
2024-08-26 component optimization
    [Bill of Materials-SiPM_acquisition_board.xlsx, Communication.SchDoc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]
2024-09-19 assembly data, sheet numbering
    [Amplifier.SchDoc, Bias.SchDoc, Communication.SchDoc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]
